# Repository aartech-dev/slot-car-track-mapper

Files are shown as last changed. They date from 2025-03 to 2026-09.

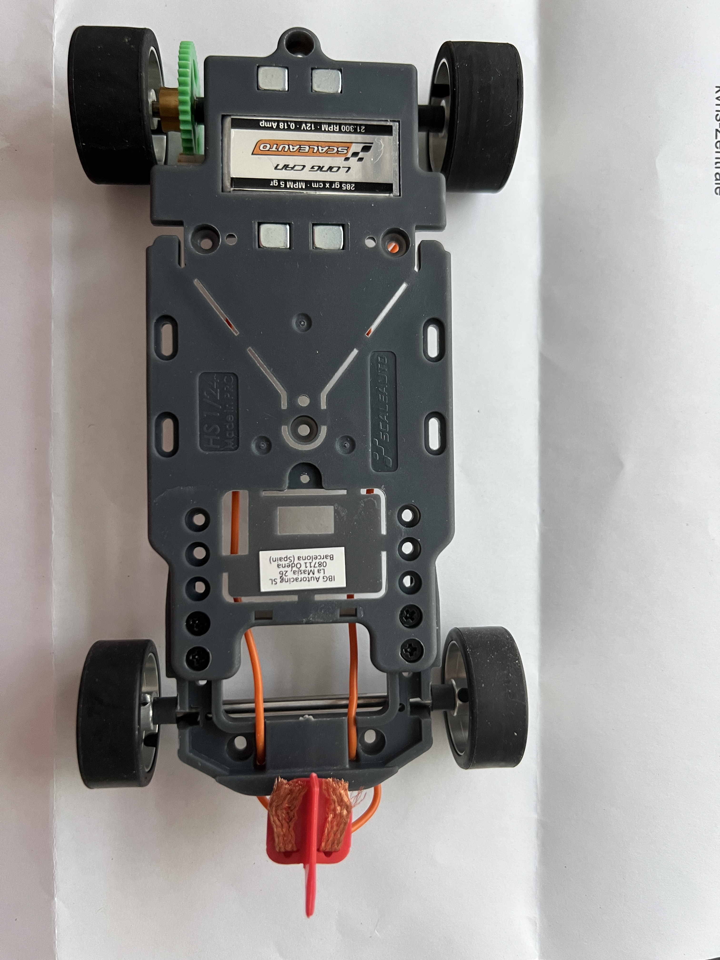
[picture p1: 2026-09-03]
tmp/scaleauto-chassis-bot.jpeg

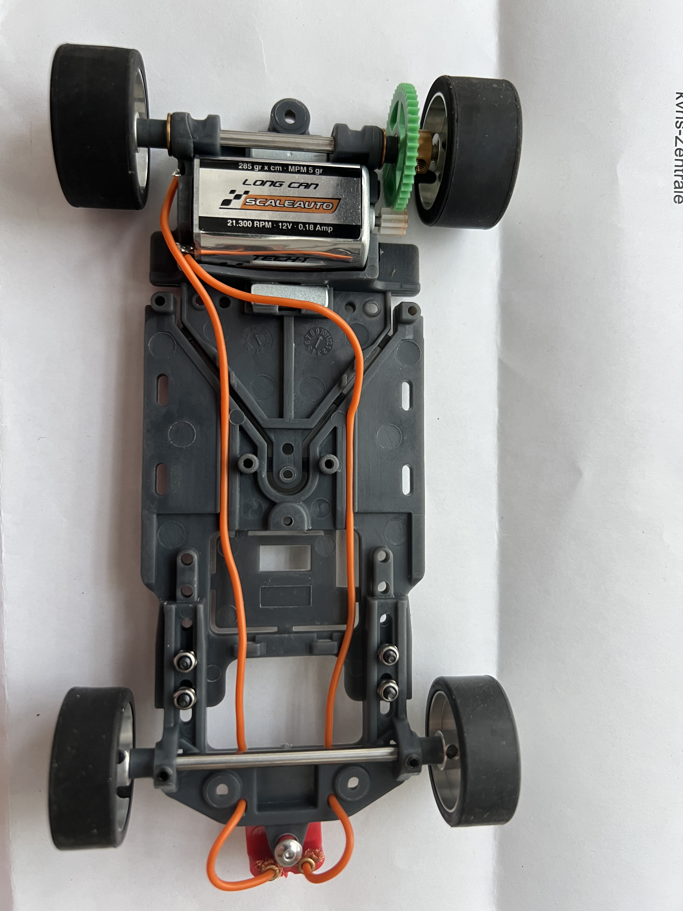
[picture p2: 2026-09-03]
tmp/scaleauto-chassis-top.jpeg

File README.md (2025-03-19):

# slot-car-track-mapper
Design for a device for mapping a slot car track by using a part from an optical mouse.

## Links

https://github.com/KMKfw/kmk_firmware/blob/main/kmk/modules/adns9800.py

https://hackaday.com/tag/adns-9000/

https://www.application-datasheet.com/pdf/broadcom/adns-6190-002.pdf   

https://www.tindie.com/products/citizenjoe/adns-9800-motion-sensor/   

https://www.reddit.com/r/Trackballs/comments/ovn849/sharing_adns9800_and_pmw3360_breakout_boards_on/   

https://sminliwu.github.io/2019/04/30/adns.html

https://github.com/kbjunky/ADNS9800   

http://pepijndevos.nl/2015/05/29/adns-9800-hookup-guide.html  

https://www.instructables.com/Arduino-Tutorial-ADNS-9800-Laser-Mouse-Traveled-Di/  

https://github.com/INITIAL7664/ADNS-9800/blob/master/firmware.ino

https://github.com/svofski/ADNS-9800-Energia/blob/master/ADNS-9800-Energia.ino

https://8051enthusiast.github.io/2020/04/14/001-USB_Firmware.html

https://github.com/mrjohnk/ADNS-9800/tree/master

https://github.com/joshuajnoble/ArduinoADNS-9800/blob/master/ADNS9800.ino

```

from machine import Pin, SPI
import time

# SPI Setup
SPI_CLK = 10
SPI_MOSI = 11
SPI_MISO = 12
CS_PIN = 13
RESET_PIN = 14

# ADNS-9800 Registers
REG_PRODUCT_ID = 0x00
REG_MOTION = 0x02
REG_DELTA_X = 0x03
REG_DELTA_Y = 0x04
REG_SROM_ENABLE = 0x13
REG_SROM_ID = 0x2A
REG_SROM_LOAD_BURST = 0x62
REG_LASER_CTRL0 = 0x20

# SPI Initialization
spi = SPI(1, baudrate=2000000, polarity=1, phase=1, miso=Pin(SPI_MISO), mosi=Pin(SPI_MOSI), sck=Pin(SPI_CLK))
cs = Pin(CS_PIN, Pin.OUT, value=1)
reset = Pin(RESET_PIN, Pin.OUT, value=1)

def write_register(register, value):
    cs.value(0)
    spi.write(bytearray([register | 0x80, value]))  # MSB = 1 for write
    cs.value(1)
    time.sleep_us(50)

def read_register(register):
    cs.value(0)
    spi.write(bytearray([register & 0x7F]))  # MSB = 0 for read
    time.sleep_us(50)
    data = spi.read(1)
    cs.value(1)
    return data[0]

def reset_sensor():
    reset.value(0)
    time.sleep_ms(10)
    reset.value(1)
    time.sleep_ms(10)

def upload_srom(srom_data):
    write_register(REG_SROM_ENABLE, 0x1D)
    time.sleep_ms(10)

    write_register(REG_SROM_ENABLE, 0x18)
    time.sleep_ms(10)

    cs.value(0)
    spi.write(bytearray([REG_SROM_LOAD_BURST | 0x80]))  # Start burst mode write
    time.sleep_us(15)

    for byte in srom_data:
        spi.write(bytearray([byte]))
        time.sleep_us(15)

    cs.value(1)
    time.sleep_ms(10)

def read_motion():
    motion = read_register(REG_MOTION)
    if motion & 0x80:  # Motion detected
        delta_x = read_register(REG_DELTA_X)
        delta_y = read_register(REG_DELTA_Y)
        return (delta_x, delta_y)
    return (0, 0)

# --- Main Execution ---
reset_sensor()

# Check product ID
prod_id = read_register(REG_PRODUCT_ID)
if prod_id != 0x33:
    print(f"Error: Unexpected Product ID {prod_id:#02x}")
else:
    print(f"ADNS-9800 detected! Product ID: {prod_id:#02x}")

# Load SROM (You need to replace 'srom_data' with actual SROM file contents)
srom_data = bytes([0x00] * 4094)  # Replace this with real SROM data
upload_srom(srom_data)

# Verify SROM
srom_id = read_register(REG_SROM_ID)
if srom_id == 0:
    print("Error: SROM upload failed.")
else:
    print(f"SROM successfully loaded. ID: {srom_id:#02x}")

# Enable Laser
write_register(REG_LASER_CTRL0, 0x80)  # Enable laser

# Main Loop to Read Motion
while True:
    dx, dy = read_motion()
    if dx != 0 or dy != 0:
        print(f"Motion detected: ΔX={dx}, ΔY={dy}")
    time.sleep(0.1)

```

## How to Use

Copy the script onto your Raspberry Pi Pico using Thonny or another MicroPython editor.
Ensure you have the ADNS-9800 SROM file (from PixArt). Replace srom_data with the actual bytes from the SROM.
Run the script. If the sensor is properly connected, you should see motion data when you move it.

## Next Steps
Fine-tune DPI settings by adjusting configuration registers.
Implement more advanced features, such as lift detection or angle snapping.
Store the real SROM file in flash memory or an SD card instead of embedding it in code.

To use the ADNS-9800 SROM file in MicroPython, you need to:

Obtain the SROM file (usually a .bin file) from PixArt or an official source.
Convert it to a byte array that MicroPython can read.
Modify the script to read the file from flash storage or an SD card.

Step 1: Convert the SROM File
If you already have the ADNS9800_SROM.bin file, you need to convert it into a Python byte array. You can do this with a Python script on your computer.

Convert SROM File to Python Byte Array

Run this Python script on your computer (not on the Pico!):

```
# Convert ADNS-9800 SROM binary to a Python byte array
srom_filename = "ADNS9800_SROM.bin"

with open(srom_filename, "rb") as f:
    srom_data = f.read()

# Format as a Python list
output = "srom_data = bytes([" + ", ".join(f"0x{b:02X}" for b in srom_data) + "])"

# Save as a Python file
with open("srom_data.py", "w") as f:
    f.write(output)

print("Conversion complete! The SROM data is saved in 'srom_data.py'.")
```

This script reads the binary file and converts it into a Python byte array.
The output is stored in srom_data.py, which you can then upload to the Pico.

Step 2: Upload the SROM Data to the Pico
After running the script, copy srom_data.py to your Raspberry Pi Pico.
Modify your MicroPython script to import the SROM data instead of defining it manually.

Step 3: Modify the MicroPython Script to Use the SROM File
Change this line in your MicroPython script:
```
srom_data = bytes([0x00] * 4094)  # Replace this with real SROM data
```

To this:
```
from srom_data import srom_data  # Import the converted SROM data
```

Alternative: Read Directly from an SROM File on an SD Card
If you have an SD card connected to the Pico, you can store the ADNS9800_SROM.bin there and read it directly:
```
def load_srom_from_sd():
    with open("/sd/ADNS9800_SROM.bin", "rb") as f:
        return f.read()

srom_data = load_srom_from_sd()
```

Final Steps
Run your MicroPython script on the Pico.
The SROM should now load properly, and the sensor should start tracking motion! 🚀
```
import os
import sdcard
import machine
import time

# SD Card SPI Configuration
SPI_SD = machine.SPI(0, baudrate=1000000, polarity=0, phase=0,
                     sck=machine.Pin(18), mosi=machine.Pin(19), miso=machine.Pin(16))
CS_SD = machine.Pin(17, machine.Pin.OUT)

# Mount SD Card
def mount_sd():
    global sd
    try:
        sd = sdcard.SDCard(SPI_SD, CS_SD)
        vfs = os.VfsFat(sd)
        os.mount(vfs, "/sd")
        print("SD Card Mounted!")
    except Exception as e:
        print("Failed to mount SD card:", e)

# Load SROM File from SD Card
def load_srom_from_sd(filename="/sd/ADNS9800_SROM.bin"):
    try:
        with open(filename, "rb") as f:
            srom_data = f.read()
        print(f"SROM file loaded: {len(srom_data)} bytes")
        return srom_data
    except Exception as e:
        print("Error reading SROM file:", e)
        return None

# --- MAIN EXECUTION ---
mount_sd()

srom_data = load_srom_from_sd()
if srom_data:
    print("SROM Data Ready to Upload to ADNS-9800!")
else:
    print("Failed to load SROM file.")
```

4. Upload the SROM File to the SD Card

Format the SD card as FAT32.
Copy the ADNS9800_SROM.bin file to the root of the SD card.
Insert the SD card into the Pico SD card module.

5. Modify Your ADNS-9800 Code

Now, update your ADNS-9800 MicroPython script to read from the SD card:

Replace this:
```
from srom_data import srom_data  # Import the SROM from a Python file
```
With this:
```
srom_data = load_srom_from_sd()
```

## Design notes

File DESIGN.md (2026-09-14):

# Design Document: Slot Car Track Mapper

Status: concept / pre-implementation. This document captures the reasoning behind the chosen sensing approach and the electrical design, so mechanical/fixture and firmware work can proceed from a shared plan instead of ad hoc experimentation.

## 1. Goal

Reconstruct the 2D shape (path) of a slot car track by carrying a sensor package around the track in a car, without any prior knowledge of the track layout. A real track has multiple parallel lanes (routed slots), and the goal is an accurate vector representation of *every* lane, not just the one driven first — §9 covers how the single-lane pipeline in §2–§8 extends to that, and what it still needs (a small manual measurement, not more sensing) to get there.

## 2. Why optical flow alone is not enough

A single optical-mouse sensor (ADNS-9800, PMW3360, PAW3395, HERO, ...) reports incremental surface displacement **in its own body-fixed axes**, not in world coordinates. A slot car follows the guide slot, so the chassis — and a sensor bolted to it — yaws to track every curve. Through most of a corner the sensor therefore sees close to pure "forward" flow, the same as on a straight. Summing those local (dx, dy) vectors as if they were already in a fixed world frame collapses curves toward straight lines: the sensor isn't wrong, it's just reporting *distance traveled*, not *track curvature*.

To recover the true path you need a heading (yaw) estimate at every sample, so each local displacement can be rotated into world coordinates before it's integrated — standard dead-reckoning. Two ways to get that heading:

1. **IMU fusion (chosen approach).** Add a gyroscope (part of any 6/9-axis IMU) and integrate yaw rate into heading. Rotate each optical (dx, dy) sample by the current heading, then accumulate world-frame position. Single sensor, single extra part, runs entirely as a firmware fusion loop on the Pico.
2. **Dual optical sensors.** Two sensors at a fixed baseline; differencing their along-track readings gives rotation directly (same principle as differential wheel-encoder odometry), no IMU needed. Rejected for v1: doubles SPI wiring and pin budget, and needs precise mechanical spacing on a 1/24-scale fixture.

Mechanical note: ideally the sensor sits directly over the car's guide-pin pivot, since that's the point whose velocity is "pure" body-frame translation. If it's offset by a vector **r** (likely, given fixture constraints), the sensor also picks up a lever-arm term from rotation: `v_sensor = v_pivot + ω × r`. Once ω (from the IMU) and **r** (measured once, fixed) are known this is a straightforward correction in the fusion loop, but **r** needs to be measured accurately when the fixture is built.

The current first-pass CAD layout (§7, `cad/fixture.scad`) places the PMW3360 18mm back from the guide-pin pivot — so `r ≈ 18mm` along the chassis centerline is the current working value for this correction, pending the layout settling down as real part dimensions replace the estimates.

## 3. Selected parts

| Role | Part | Why |
|---|---|---|
| Microcontroller | **Raspberry Pi Pico 2 W** | RP2350: same CYW43439 WiFi as plain Pico W, so `wifimanager.py`'s `network.WLAN` code runs unmodified — chosen over an ESP32 to avoid WiFi-radio scheduling jitter competing with the sensor-fusion polling loop on the same cores. Adds a hardware FPU (Cortex-M33, unlike the RP2040/original Pico's M0+), which directly speeds up the fusion loop's per-sample rotation trig (§6). 520KB SRAM (vs. RP2040's 264KB) gives headroom for the path buffer/logging. Same Pico form factor and largely the same GPIO layout as the original Pico, so `main.py`'s existing pin constants likely carry over without remapping. Considered and rejected: ESP32 (mature MicroPython WiFi, but shares compute with the sensor loop, and requires a full pin remap), Arduino Nano RP2040 Connect (tempting onboard IMU, but its WiFi is a separate NINA module without native MicroPython `network` support — would break `wifimanager.py`). |
| Optical flow sensor | **PMW3360** | Large open-source driver base from mouse-modding/DIY-odometry projects. Performance is comparable to ADNS-9800 and well beyond what slot car speeds need either way. **Correction:** this row originally also claimed "no mandatory SROM firmware upload" as a reason to prefer it over the ADNS-9800 — that's wrong. Every reference PMW3360 driver uploads an SROM firmware blob on power-up via `SROM_Load_Burst`, the same as the ADNS-9800 (see `pmw3360.py`). The SROM step doesn't go away; it just isn't a *worse* bring-up than the ADNS-9800's, so it wasn't actually a differentiator either way. |
| IMU | **ICM-42688-P** | 6-axis gyro+accel with notably lower gyro bias/noise than the ubiquitous MPU6050 — directly reduces the heading-integration drift that's the main source of mapping error in this design (§2). Similar price/I2C-breakout availability to MPU6050. |

The optical sensor and IMU were chosen over alternatives considered (ADNS-9800 kept for reuse, PAW3395 for raw performance, MPU6050 for ubiquity, BNO085 for onboard fusion) mainly on integration risk vs. payoff at this project's actual requirements — see conversation history for the full comparison if reconsidering later.

**Consequence:** `main.py`'s ADNS-9800 SPI register map and `a6_binary.py`'s extracted SROM firmware are now superseded, replaced by `pmw3360.py`'s PMW3360 driver — including its own real SROM 0x04 firmware (sourced from SunjunKim/PMW3360, no longer a placeholder). `a6_binary.py` is left in place as a worked reference for the general SPI-register bring-up pattern (reset → verify product ID → init → poll) and the vendor-SROM-to-Python-array conversion technique it demonstrated, both of which carried over, along with the pin constants (subject to confirming the Pico 2 W's pinout matches).

### Electrical schematic and concrete pin assignments

`electronics/electronics.kicad_sch` is the single-sheet system schematic covering every component above plus the power chain (§4): rail input → reverse-polarity diode → buck-boost regulator → Pico VSYS, with a supercap on the regulated 5V rail and an unmodified tap to the stock motor. The PMW3360, ICM-42688-P, IR reflectance sensor, and the buck-boost regulator don't have real breakout-specific KiCad symbols, so they're drawn as generic pin-header connectors labeled by net — see the file's own text notes for what's a real part symbol (Pico 2 W, using the pin-compatible RP2040 `RaspberryPi_Pico` library symbol) versus a documentation stand-in. Passes ERC clean (0 violations) with explicit no-connect flags on every intentionally-unused pin.

Cross-checked against Ploopy's open-hardware trackball designs (`ploopyco/classic-trackball`, CERN-OHL-1.2, `hardware/Electronics/Schematics/Base-R1_005.pdf`), which wire the bare PMW3360DM-T2QU chip directly on a real shipped product. Their `MouseSensor.SchDoc` needs three separate rails — VDD 1.8V, VDDIO 3.3V (matched to host logic), and VDDPIX 1.8V fed through a 22Ω+22Ω filter with 10uF/0.1uF decoupling right at the pin — plus a 10k pull-up from CS to 3V3 so the sensor stays deselected before the MCU's GPIO drives it high. That VDDPIX filtering requirement is a concrete reason this project's plan to buy a PMW3360 *breakout* (BOM.md) rather than lay out the bare chip is the right call — a decent breakout hides that three-rail circuit behind its own onboard 1.8V regulator and exposes a single VCC. Two things worth carrying over onto our own board regardless: add the same CS-to-3V3 pull-up once a real PMW3360 breakout symbol replaces the generic connector (§8), and when that breakout is actually sourced, check whether it truly hides VDD/VDDIO/VDDPIX internally or expects them wired separately — cheap DIY-mouse-mod modules vary on this.

Drawing it forced concrete GPIO assignments, which now supersede the vague "SPI0"/"I2C0" labels used earlier in this document:

| Signal | Pico 2 W pin |
|---|---|
| SPI0 SCK / MOSI / MISO / CS → PMW3360 | GPIO10 / GPIO11 / GPIO12 / GPIO13 |
| PMW3360 MOTION (interrupt) | GPIO14 |
| I2C0 SDA / SCL → ICM-42688-P | GPIO4 / GPIO5 |
| ICM-42688-P interrupt | GPIO6 |
| IR reflectance sensor output | GPIO26 (ADC0) |

The SPI pins land on the exact same GPIOs `main.py` already uses for the ADNS-9800 (`SPI_CLK=10, MOSI=11, MISO=12, CS=13`) — but GPIO14, previously the ADNS-9800's `RESET_PIN`, is repurposed as the PMW3360's motion-interrupt input (the PMW3360 has no reset pin). That's a change in *meaning*, not just reuse — flag it clearly when the firmware is rewritten so it isn't mistaken for a leftover reset line.

Per §2's environmental note: configure the ICM-42688-P (or any future IMU swap) for gyro+accel only — no magnetometer is on this part, so the mag-interference risk from the motor magnets doesn't apply here, which is one more point in its favor over 9-axis parts.

## 4. Power: analog controllers change the constraint

Confirmed: controllers are analog (resistive/linear throttle), not PWM. That means rail voltage is a clean, un-chopped DC level — but one that is *intentionally* proportional to trigger position, from ~0 V (stopped) up to full pack voltage (typically 12–18 V) at full throttle. This is a harder power problem than a PWM system, not an easier one: there is no fixed high-frequency carrier to hold electronics up between pulses, because at low throttle there may genuinely be almost no rail voltage at all.

Implications:

- A simple buck regulator won't work across the whole range — it can't produce 3.3/5 V once the input sags below its dropout, which will happen exactly when the car is slow or stopped.
- A **buck-boost** regulator (e.g. TI TPS63070-class, ~0.9–18 V in) extends the usable range down much further, but still has a floor near true 0 V.
- Below that floor, only stored energy keeps the electronics alive.
- No shortcut via a separate accessory rail: slot car tracks never carry a third, constant-voltage rail alongside the two throttle rails — cars with lights or other accessories run them off the same variable throttle rail, not an independent supply. So the buck-boost + supercap design below is the actual answer to this problem, not a fallback for when a nonexistent easier option isn't available.
- Include basic input protection (reverse-polarity diode / small TVS) regardless of source — pickup shoes can momentarily bridge or reverse polarity on crashes/spin-outs.

### Energy buffer: supercapacitor (selected)

**Decision: a single supercapacitor, not a LiPo battery**, sized to ride through brief low-throttle/contact-loss moments during an active mapping lap — not to keep the device alive for extended parked periods, which isn't this project's requirement. Reasoning:

- **Simplicity:** a supercap needs no charge-management *IC*, no protection circuit, and no power-path chip — at most a resistor and a diode (below), not a dedicated chip. A LiPo needs all three (charger IC, protected cell, ideally a power-path chip to avoid a hard switchover between rail power and battery power) for a small cost/weight saving that doesn't matter here.
- **Crash safety:** slot cars hit barriers. A punctured/crushed LiPo pouch is a real fire risk; a damaged supercap is not. This matters more here than in most projects.
- **Fit to duty cycle:** supercaps self-discharge faster than LiPo and don't hold charge for long-term storage — irrelevant for a device that's only ever active while running on the track, where it's continuously recharged during every high-throttle segment.

**Placement — regulator output, not regulator input:** don't connect the supercap directly across the raw rail; the rail swings up to full pack voltage (12–18 V), well above a single 5.5 V-rated cell, and multi-cell series stacks need balancing (reintroducing the complexity being avoided). Instead:

```
rail → [buck-boost regulator] → 3.3V/5V logic rail → Pico/sensors
                                        |
                                  [R1] (charge current limit)
                                   |       |
                                  [D2] ---‖ (bypasses R1 when the cap is
                                   |          discharging — ride-through
                              [supercap]     current isn't limited by R1)
```

Size the cap with `C = I × t / ΔV`: at a rough 80–100 mA logic load, accepting the rail sagging from 3.3 V to ~2.7 V before it's risky, a 1 F/5.5 V cell (~$1–2) buys a few seconds of full ride-through with zero rail voltage; a 10 F/5.5 V cell (~$2–5) buys tens of seconds.

**Charging isn't free, though, and it isn't just "the regulator's current limit handles it."** Connecting a fully-discharged cap directly to a live regulator output looks like a near dead-short for the first instant — worth limiting explicitly rather than trusting an unspecified regulator's behavior. `electronics/electronics.kicad_sch` adds:

- **R1** (provisionally 4.7Ω) in series between the regulated rail and the cap, limiting charge inrush.
- **D2** (Schottky) in parallel with R1, oriented so the cap can *discharge* back into the rail through D2's low forward drop instead of through R1 — otherwise R1 would eat into the very ride-through voltage margin the cap exists to provide.

This means charge time is now an `R1 × C1` problem, not just a regulator-current problem — and it cuts the other way from the ride-through sizing above: `t_charge ≈ 5 × R1 × C1` (5 time constants ≈ full charge). With R1 = 4.7Ω: a **1F cap charges in ~24s**; a **10F cap would take ~4 minutes** — long enough that the device wouldn't have its ride-through protection for the first few minutes of every session. **This pushes the practical choice toward the 1F end of the range above, not the 10F end**, unless R1 is reduced (which weakens inrush protection) — the two were sized independently earlier in this doc and need to be sized together. Revisit both once a real regulator's current limit is known (its datasheet may make R1 unnecessary or let it shrink).

**Reconsider LiPo only if** the requirement changes to "must stay powered for minutes with no rail contact" (e.g. logging while parked in the pits) — a supercap can't do that in a small/cheap package. If that happens: single protected 1S cell (100–150 mAh) + a linear charger IC (MCP73831-class) + ideally a power-path chip (BQ24075-class) to charge and run simultaneously without switchover glitches. Budget for ongoing battery-health concerns then too (over-discharge cutoff, cycle-life fade, no long-term full/empty storage).

See `electronics/electronics.kicad_sch` for the R1/D2/C1 sub-circuit as drawn (ERC-clean).

## 5. System block diagram (IMU fusion option)

```
                    TRACK RAILS (analog DC, ~0-18V, varies with throttle)
                              |                    |
                              v                    v
                   +---------------------------------------+
                   |     Pickup shoes / contact braids      |
                   +---------------------------------------+
                              |                    |
                              v                    v
        +----------------------------------------------------------+
        |          reverse-polarity protection (diode/TVS)          |
        |          buck-boost regulator, Vin ~0.9-18V -> 3.3V/5V    |
        +----------------------------------------------------------+
                              |
                              v  regulated 3.3V/5V rail
                              +---------------------------+
                              |  supercap (5.5V-rated),    |
                              |  rides out low-throttle /  |
                              |  contact-loss dips         |
                              +---------------------------+
                              |
        +----------------------------------------------------------+
        |               Raspberry Pi Pico 2 W (RP2350)               |
        |                                                            |
        |  SPI0 (CLK/MOSI/MISO/CS, RESET) -------------------------->|---> Optical flow sensor
        |                                                            |     (PMW3360) mounted over
        |                                                            |     track surface, at/near
        |                                                            |     guide-pin pivot
        |                                                            |
        |  I2C0 (SDA/SCL) ------------------------------------------>|---> IMU (ICM-42688-P,
        |                                                            |     gyro + accel), rigidly
        |                                                            |     mounted, axes aligned to
        |                                                            |     chassis forward/lateral/
        |                                                            |     vertical
        |                                                            |
        |  GPIO/ADC ------------------------------------------------>|---> IR reflectance sensor
        |                                                            |     (TCRT5000/QRE1113),
        |                                                            |     mounted alongside PMW3360,
        |                                                            |     reads start/finish marker
        |                                                            |
        |  [optional] SPI1/SD -------------------------------------->|---> onboard logging (SD/flash)
        |  [optional] onboard WiFi (wifimanager.py) ----------------->|---> base station / laptop
        +----------------------------------------------------------+
```

## 6. Firmware fusion loop

Implemented in `main.py` (with `pmw3360.py` and `icm42688.py` as the sensor drivers) — not yet tested on real hardware, see those files' own caveats. Per sample tick:

1. Read gyro yaw rate from IMU; integrate into heading `θ`.
2. Read (dx, dy) from optical sensor (body frame); apply the lever-arm correction `v_pivot = v_sensor − ω × r` using this tick's rotation and the measured mounting offset **r** = 18mm (CAD, §2, §7).
3. Rotate the corrected (dx, dy) by `θ` into world coordinates; accumulate into running position (X, Y).
4. Write (t, X, Y, θ, lap) as a CSV row to flash on every tick, flushed every 50 samples — chosen over "buffer everything, write once at the end" specifically because this project's own power story (§4) means a mid-run brownout is a real, not theoretical, risk; buffering it all in RAM would lose an entire run to a single dropout.
5. On lap-trigger detection (below), reset accumulated position to (0, 0) — the marker's own location, since that's what defines the origin; heading `θ` is left as-is (the trigger carries no direction information — see below).

Calibration this first pass still needs (not yet possible without hardware in hand): `LAP_THRESHOLD` tuned against the real IR marker's light/dark ADC values, and a by-hand sanity check that the gyro sign and the optical sensor's dx/dy axes match the code's assumed convention (documented at the top of `main.py`) — get either wrong and the map will be systematically distorted in a way that's easy to misattribute to the physics instead. (The PMW3360 SROM firmware is no longer on this list — `pmw3360.py` now has the real SROM 0x04 blob, not a placeholder.)

`pmw3360.py`'s driver has also been cross-checked against QMK's PMW33xx driver (`qmk/qmk_firmware`, `drivers/sensors/pmw3360.c`/`pmw33xx_common.c`), deployed on real trackball keyboards using this sensor. QMK doesn't carry the SROM byte content in-tree either (dropped for licensing, opt-in and keyboard-supplied from this same SunjunKim/PMW3360 source), so it can't confirm `SROM_FIRMWARE` byte-for-byte — but its constants do corroborate it: firmware length (4094 bytes) and product/inverse-ID signature (0x42/0xBD) both match, and its register map agrees address-for-address. Two init-sequence details this port was missing got folded in as a result: the NCS power-up toggle before `Power_Up_Reset`, and more conservative post-write settle timing — both proven across QMK's real-hardware deployments, still unverified here on this project's own board.

### Gyro-bias calibration (at power-up)

**Implemented in `main.py` as `calibrate_gyro_bias()`, run once at startup before the fusion loop begins.** `sim/simulate_track_run.py` (built to generate expected sensor data for the real Bolton club track, §6/§8) modeled a deliberately modest, realistic 0.3°/s uncalibrated gyro bias and found it responsible for roughly **320mm of reconstructed-position error by the end of a single 12.5s lap** (isolated by re-running the simulation's own closing-error check with the bias zeroed: ~1080mm with the bias present vs. ~750mm without it) — comparable to, and in the same direction as, the optical sensor's own noise contribution. *Correction: an earlier version of this section attributed the entire ~1.1m closing error to gyro bias alone; isolation testing during implementation showed the remaining ~750mm is a baseline artifact of the simulation script's own heading-synthesis method (see `HEADING_WINDOW_MM`'s caveat comment in `sim/simulate_track_run.py`), not something attributable to gyro bias, noise, or a defect in the fusion algorithm itself — flagged in case a future pass re-derives these numbers and gets a different split.* Either way, the lap-reset (below) hides the bias's within-lap effect by zeroing (X, Y) at each marker crossing, but it does nothing for heading, which keeps accumulating the same bias lap after lap; any use of the map beyond "one lap's shape" (comparing laps, averaging them, trusting absolute heading) needs this fixed at the source.

**Design (as implemented):**

1. **Before the run starts, with the car held stationary** (on the bench or sitting still in the slot), sample the gyro Z axis for a short fixed window (`GYRO_CAL_DURATION_MS`, 1.5s) and average the readings to estimate the static bias `gz_bias`.
2. **Subtract `gz_bias` from every raw gyro reading** before integrating it into heading, for the remainder of that run. This runs fresh at the start of every `run()` call rather than storing a calibration constant across runs/power cycles — gyro bias drifts with temperature and time, so yesterday's measured bias is not a safe stand-in for today's.
3. **Verify stillness during the calibration window** using the accelerometer already being read for other purposes (§3/§6) — `calibrate_gyro_bias()` checks its combined variance over the window against `GYRO_CAL_MAX_ACCEL_STD_G` and prints a `MOVED -- calibration unreliable` warning rather than silently baking a bad bias into the whole run (it doesn't yet block/retry the run automatically — that's a possible follow-up once real accelerometer noise floor data says what threshold is actually reliable).
4. **Limitation, by design:** this corrects the *static* bias present at power-up, not in-run bias wander — it's a start-of-run correction, not a continuous one. A zero-velocity update (detecting known-stationary moments during a run, e.g. the car briefly stopped) would address in-run wander if it turns out to matter — not needed for v1, noted here so it isn't forgotten if lap-to-lap heading error looks worse than this calibration alone can explain.

### Closed-loop heading correction (offline, per completed lap)

At-rest calibration (above) only removes the bias present *before* the run starts — it does nothing for bias that wanders during the run, and `tools/plot_track_csv.py`'s overlay view made the consequence visually obvious: the reconstructed path bows away from the true track shape, worst through the tightest sections, because nothing ever corrects *heading* mid-lap (only position resets, at the marker).

**The fix needs no new hardware, because a lap is a closed curve.** The car's net heading change over one complete lap is a known geometric quantity, not a free parameter — for a lane whose own centerline is a simple loop (no self-crossing), it's exactly ±360° per lap; for a lane that crosses itself once, it's a different, still-computable value (0° for a simple figure-8-style self-crossing). Whatever it is, the *difference* between that known value and what the lap's logged heading actually did is attributable to gyro bias/wander during that lap, and can be removed by re-integrating the whole lap with a constant correction spread over its elapsed time.

**Important nuance on what "crosses itself" means, since most real tracks have a crossover:** a lane-swap crossover piece (common — used to equalize total lane lengths, since a permanent inside lane would otherwise be shorter than the outside one) makes one lane's centerline cross *another lane's*, not its own. Each individual lane is typically still a simple loop (±360° net turn) despite the crossover. Only a lane whose *own* centerline genuinely loops back and crosses itself gets a different value — determine which case applies by inspecting the actual driven lane, not just whether the track has a crossover piece at all. `tmp/bolton-track.svg`'s "yellow" lane, used throughout this project's simulation, turns out to be the self-crossing case: computing its net turning directly from the SVG geometry (not guessed) gives exactly **0°**, not ±360° — confirming this needs checking per track, not assumed.

**Implemented as `tools/closed_loop_correct.py`, run offline on a downloaded `track_log.csv`, not on-device.** It turns out no firmware change is needed to support this: `main.py` already logs `theta_rad` continuously (never reset, only `x`/`y` reset at the marker), so the raw per-tick heading change is recoverable directly from consecutive log rows, and the per-tick body-frame translation is recoverable by inverse-rotating consecutive `(x, y)` deltas by the logged `theta_rad` — enough to fully re-integrate a lap with a corrected heading trace. This also keeps the correction properly offline: it needs a *complete* lap's total turning and elapsed time before it can compute anything, which doesn't fit `main.py`'s incremental streaming-write design (deliberately real-time and brownout-safe, §6) — so it stays a separate post-processing step rather than something attempted live on the Pico.

**Validated in simulation** (`sim/simulate_track_run.py` now also emits `sim/expected_firmware_log.csv`, formatted exactly like the real on-device log, for this purpose): running `tools/closed_loop_correct.py --net-turns 0.0` on that simulated log reduced the closing error from ~1120mm to ~700mm (roughly **-40%**), and reduced the worst-point deviation from the true path by a comparable margin. It does not eliminate the error — the remainder is gyro random-walk noise (not fixable by a constant per-lap correction) plus a heading-synthesis artifact specific to how the simulator generates its synthetic gyro data.

**Lap length, and multi-lap averaging.** The same tool reports each corrected lap's length in meters (arc length of its own reconstructed path) and the mean/spread across however many laps were recorded — on a simulated 5-lap run this came out as 36.349m mean with only a 32mm spread lap-to-lap, close to (though not exactly) the track's true 35.9664m (118ft), the residual gap being the same heading-synthesis artifact mentioned above. `--average-out` additionally resamples every corrected lap onto a common arc-length parameterization and averages them into one smoothed shape, for a visually cleaner map — but its own length figure isn't more trustworthy than the simple per-lap mean: it came out to ~36.9m on the same test data, higher than the 36.349m mean, because the averaging doesn't correct for small heading-orientation differences between laps before combining them. Use the per-lap mean as the lap-length measurement; treat the averaged shape as a visualization aid. The full data-collection-to-post-processing procedure is `BRINGUP.md` Stage 11.

### Lap-detection mechanism (selected)

**Decision: onboard active-IR reflectance sensor (e.g. TCRT5000/QRE1113-class) reading a physical contrast marker (tape strip) laid across the track at the start/finish line.** Mounted on the car alongside the PMW3360, near the guide-pin pivot — the guide pin tightly constrains lateral position, so the sensor sweeps the same physical point on the marker every lap with no alignment tolerance needed.

Rejected alternatives and why:
- **Software-only ("near starting X,Y after N seconds")** — circular: uses the very dead-reckoned position that's drifting to decide when to correct it. Breaks outright on a self-crossing layout (figure-8), where "near start" is ambiguous.
- **Hall sensor + embedded magnet** — the motor's own permanent magnets sit right next to the mounting location; a simple threshold Hall switch can't reliably separate "external track magnet passing underneath" from "background field from my own motor." Same interference family already ruled out for magnetometer fusion (§3).
- **Mechanical lever/bump strip** — physical obstruction on the track, wear over many laps, risk of inconsistent engagement (bounce/skip).
- **External trackside IR gate** — moves the sensor off the car, but the correction has to be applied *onboard* where the dead-reckoning state lives, so it still needs a real-time wireless link back to the car, plus trackside alignment every time the layout is reconfigured. More moving parts than a sticker.

Active-IR reflectance (emits and reads its own reflected IR) is immune to ambient lighting, unlike a bare phototransistor, and the module is sub-$1 with a simple GPIO/ADC read.

**Limitation:** a single marker crossing gives a position reference only, not heading — heading keeps relying on the ICM-42688-P's gyro integration between corrections. If heading drift becomes visible over many laps, a second marker a short known distance downstream would let the time-of-flight between the two triggers derive an instantaneous heading correction too — a future upgrade, not needed for v1.

**Debounce:** ignore any trigger occurring less than some fraction of the expected lap time since the last one, so a wide/uneven marker edge or a bounce doesn't double-fire the correction.

**Tape width — size it to the sampling, not just to "wide enough to see":** `main.py`'s loop is unthrottled (no `sleep()`), so its real sample period is whatever SPI+I2C+math+logging overhead works out to on real hardware — not yet measured (§8). `sim/simulate_track_run.py`, at its 100Hz assumption and ~3 m/s tape-crossing speed, showed only **1 sample** landing above `LAP_THRESHOLD` with a 12mm tape — a single missed sample (loop jitter, a slightly faster pass) means a missed lap entirely.

The sizing rule: for a loop sampling at period `T` and a car crossing at speed `v`, any tape narrower than `v·T` (in the direction of travel) can fall entirely between two samples and be missed outright; `2·v·T` guarantees at least one sample with some margin either side of exact alignment. E.g. at `v`=3–6 m/s and an assumed `T`=10ms (100Hz, itself unverified — see above): 30–60mm for a bare guarantee, 60–120mm for margin.

**Recommendation: start with a 40mm-wide tape strip** (re-confirmed against `sim/simulate_track_run.py`, which now catches 2 samples at its simulated pace with this width) as a practical starting point, and revisit against the *measured* loop period once real hardware timing is in hand (§8) — narrower is fine if the real loop turns out faster than 100Hz, wider is needed if slower. Driving a controlled, less-than-flat-out pace specifically across the line (lower `v` at the crossing) directly buys the same margin as a wider tape, per the same formula, and costs nothing to try first.

## 7. Fixture: donor chassis conversion

**Donor:** Scaleauto HS-124 Universal Complete Chassis (plastic, sidewinder, variable wheelbase 96–114mm). Measured on the chassis in hand: wheelbase 114.25mm, rear track width (outside-to-outside) 80.72mm, front track width (outside-to-outside) 77.83mm, main chassis spine width 55mm, V score-line to (former) front axle centerline 47mm, front axle centerline to guide-flag tip 18mm, spine plastic thickness at the cut face 3.6mm, guide-flag pivot peg 3.8mm diameter × 7mm engagement depth. Sidewinder layout: motor mounted along the chassis's long axis driving the rear axle through a pinion/spur gear pair; guide flag at the front doubles as the mechanical slot-engagement piece *and* the power pickup (its braids feed two wires running the full chassis length back to the motor terminals).

**The caliper measurements matter beyond just accuracy:** the replaceable front section is only 65mm long (47+18mm) — barely half of the ~112mm first guessed from photos. That's tight enough to change the layout, not just tune it: the Pico 2 W's 51mm length alone would eat most of the available space if mounted the "normal" way (long axis along the direction of travel), so `cad/fixture.scad` now mounts it rotated 90° — long axis running across the fixture's width — trading length for width, which the flared deck has to spare. See the CAD subsection below.

**Plan:** cut the chassis at its molded score line ("the V") in front of the motor box. Keep the rear section (motor + driven axle/wheels) stock and unmodified — propulsion is untouched. Replace the front section with a custom-fabricated fixture carrying the Pico 2 W, PMW3360, ICM-42688-P, and IR reflectance lap sensor (§3, §6), plus the guide flag.

Requirements this imposes on the fixture, beyond sensor mounting:

- **Preserve the guide flag's pivot mount.** It self-centers in the slot on a small pivot peg in the stock chassis; that compliance is part of how the car tracks corners. Rigidly fixing it instead of carrying the pivot over risks poor cornering or the flag popping out of the slot.
- **Reuse the guide flag's pickup braids as the rail power tap.** They're already the existing power path into the car — splice the buck-boost regulator's input into the same two wires (or a shared node) feeding the motor, rather than adding a separate tap. Cutting the chassis severs the existing wire run regardless, so this re-routing has to happen either way.
- **Bridge the cut structurally, not just electrically.** Removing the scored section removes the plastic that transmitted chassis stiffness between front and rear — the fixture needs to mechanically splice the two halves back into one rigid chassis, not just sit alongside the rear section.

**Front support: sled/skid (selected over small idler wheels).** The stock front wheels are non-driven idlers to begin with (the slot does the steering), so removing them is low-risk, and skid/floating front ends are already a precedented technique in the hobby (e.g. F1-style slot chassis). The decisive reason for this project specifically: a skid lets the optical sensor's standoff height be referenced directly off the same molded contact surface that sets ride height, rather than being at the mercy of separate bearing/axle/suspension play — one less independent source of variance in the one dimension (sensor-to-track distance) this whole design most needs to hold constant.

Design constraints that follow from choosing a skid:

- **Two contact points (or one wide skid), not a single central point**, spaced at roughly the stock front track width (77.83mm outside-to-outside) — a single-point skid can rock side-to-side, and that rocking would inject false roll into both the optical flow reading and the IMU.
- **Rounded/ski-tip leading edge**, not a flat/sharp one — track-piece seams are exactly where small height discontinuities occur, and a flat skid edge is more likely to catch on a proud seam than a rounded one is to bridge it.
- **Low-friction, wear-resistant skid material** (e.g. PTFE tape or a bonded Delrin/POM insert) — sliding friction is higher than rolling friction, and unlike a wheel, a worn skid directly lowers ride height (and therefore sensor focus distance) over time.
- **Reference the sensor mount to the skid, not to an independent chassis datum** — mount the PMW3360's standoff at a fixed distance from the skid's own contact plane on the same molded part, so the two stay coupled even if the skid wears.

**Open risk to validate once a prototype exists (not blocking the design, just untested):** sliding stick-slip friction can produce higher-frequency vibration than a rolling contact would, which could show up as noise in the optical flow and accelerometer readings. If that turns out to be a real problem in practice, the mitigation is a material/geometry change to the skid tip, not a redesign of the fusion approach.

**Second guide, added: a dummy pin behind the PMW3360, bracketing it between two slot-engaged points.** The stock front guide flag keeps its existing role unchanged (slot engagement + power pickup via its braids). The problem it doesn't solve on its own: with only one slot-constrained point, the fixture's orientation between there and the rear splice is otherwise set by whatever the stock rear wheels happen to be doing on the open track surface — friction- and grip-dependent, and prone to skid/slip exactly where it matters most, through the tight corners. None of §2's fusion model or `sim/simulate_track_run.py`'s error simulation accounts for that; both assume the guide-flag position (hence the sensor, via the lever-arm correction) tracks the slot centerline directly. A second, independently-pivoting pin — hard plastic, no wiring, purely mechanical — placed behind the PMW3360 makes that assumption true by construction for the sensor-carrying section: its orientation is then set entirely by two points of slot geometry, not by rear-tire grip.

Sizing the spacing between the two guides means checking against the track's *actual* tightest curve, not an assumed one — computed directly from `tmp/bolton-track.svg` across all four lanes (not just the "yellow" lane used elsewhere in this project's simulation work), the minimum radius is **221.1mm on the red lane**, tighter than yellow's 370mm and lime/blue's ~260-270mm. Given a slot as narrow as 2.5mm and a 1mm-wide hardbody-style pin for the new guide, available clearance is (2.5 − 1)/2 = **0.75mm per side**. For two independently-pivoting points rigidly separated by distance `L`, both riding the same curve of radius `R`, the geometric mismatch that would force one against its slot wall is `L³/(24R²)` (the gap between the rigid chord length and the true arc length between the corresponding points on the curve) — at the fixture's current ~49.5mm guide spacing (`cad/fixture.scad`'s `guide_spacing`) against the worst-case 221.1mm radius, that's **≈0.10mm, under 14% of the 0.75mm budget** — comfortable margin, with headroom to spare (the mismatch doesn't reach the full budget until spacing approaches ~96mm, well beyond anything this fixture needs). The other quantity this could be confused with — sagitta, `L²/(8R)` — is larger (≈2.4mm at this spacing) but doesn't apply here: it's the deviation a *rigid, non-pivoting* structural member spanning the two points would see, and nothing in this design has such a member reaching into the slot — only the two independently-pivoting pin tips do.

**This only holds if the second guide pivots freely**, the same requirement §7 already states for the front one — a rigidly-fixed (non-pivoting) second pin would face a real angular mismatch against the local slot tangent (≈8.4° at this spacing and the worst-case radius) and would genuinely bind. A loose, rotating pin in its mount (not glued, matching the front guide's own "MUST preserve the free pivot" rule) absorbs that the same way real single-guide slot cars already absorb a changing slip angle through every corner.

`cad/fixture.scad`'s `rear_guide_mount()` implements this, positioned in the ~2.3mm-wide gap that's actually available between `rear_splice()` and `pico_mount()`'s board edge (checked by explicit bounding-box comparison during layout, not by eye — the first placement attempt used a wider boss and left only a 0.3mm window, tight enough to be worth flagging as a lesson for future changes to this area of the layout).

### CAD model

`cad/fixture.scad` is the parametric OpenSCAD model implementing this section: rear splice tab, a deck that flares from the 55mm spine width out to the 77.83mm front track width (so the skids actually land on structure instead of floating past a narrow deck's edge), Pico 2 W + ICM-42688-P mounted on top, PMW3360 + IR reflectance sensor hanging below near the guide-flag pivot, the two ski-tip skid pads, and the second (dummy) guide pin behind the PMW3360 (above). All donor-chassis dimensions in the file are now from calipers (this section's opening paragraph); the component footprints (Pico/PMW3360/ICM-42688-P/IR module exact sizes) are still typical/placeholder values pending the actual parts bought, and `rear_splice()` is still a placeholder lap joint pending the real spine cross-section/rib profile — not print-ready on either count yet.

Render previews with e.g. `openscad --autocenter --viewall -o preview.png cad/fixture.scad`; the file's `echo()` statements print the computed total length, the resulting lever-arm `r` (§2), and flag if a sensor standoff or the Pico's mounting zone comes out negative/too tight.

## 8. Open items before build

- Measure/fix the sensor-to-pivot offset **r** once the fixture is machined.
- Apply the start/finish marker to the track and record its true (X₀, Y₀) as the mapping origin. Start with a 40mm-wide tape strip (§6's sizing rule) and re-check it once the real loop period and approach speed are measured.
- Measure `main.py`'s actual achieved loop period on real hardware (it's unthrottled — no `sleep()` — so this is currently unknown, not just uncalibrated) and re-run §6's tape-width sizing formula against the real number.
- Measure real logic-rail current draw on the built fixture and size the supercap (§4) from it rather than the rough estimate.
- Source PMW3360, ICM-42688-P, IR reflectance sensor, Pico 2 W, and buck-boost regulator/supercap parts and confirm they all physically fit the 1/24 fixture footprint.
- Confirm the real Pico 2 W board's GPIO pin numbering matches the RP2040 `RaspberryPi_Pico` library symbol used in the schematic (§3 addendum) and now hard-coded in `main.py`.
- Run `main.py` on real hardware for the first time and work through its documented calibration steps: `LAP_THRESHOLD` against the actual IR marker, the gyro-sign/optical-axis sanity checks, and confirm `calibrate_gyro_bias()`'s stillness threshold (`GYRO_CAL_MAX_ACCEL_STD_G`) against the real accelerometer's noise floor (§6).
- Calibrate the PMW3360's actual CPI-to-distance conversion by rolling a known distance, rather than trusting the nominal CPI setting in `pmw3360.py`.
- Get the actual PMW3360, ICM-42688-P, and IR reflectance breakout boards and replace `cad/fixture.scad`'s typical/placeholder footprint dimensions with real ones (donor-chassis dimensions are now measured — this is the remaining unverified category).
- Redesign `rear_splice()` in the CAD model as a real tongue-and-groove or screwed lap joint once the stock spine stub's cross-section (thickness, ribs) is measured — 3.6mm is the flat thickness at the cut face, not the full joint profile.
- Double-check the Pico 2 W's real board+header footprint (not just the bare PCB outline) against the ~2mm per-side clearance the rotated mount currently has in the 55mm-wide spine section — tight enough to matter.
- Prototype the skid and check for stick-slip vibration in practice (§7's open risk) before committing to a final skid material/geometry.
- Print/fabricate the front fixture from the finalized CAD model.
- Design the mechanical splice + wiring re-route across the cut (§7) between the new front fixture and the stock rear motor/drive section.
- Pick an actual buck-boost regulator part (§4 says "TPS63070-class" illustratively; `electronics/electronics.kicad_sch` represents it as a generic labeled connector) and, once chosen, swap in its real symbol/footprint.
- Re-size R1 and C1 together once that regulator's real current limit is known (§4) — R1=4.7Ω/C1=1F is provisional, picked before either the regulator or the cap was final.
- Same for the PMW3360/ICM-42688-P/IR reflectance breakout boards in the schematic — generic connectors for now, real symbols once specific boards are bought (tie this to the CAD footprint task above).
- Add a 10k pull-up from CS to 3V3 on the PMW3360 net once its real symbol replaces the generic connector, and confirm the sourced breakout's power pins (does it expose VDD/VDDIO/VDDPIX separately, or hide them behind an onboard 1.8V regulator?) — §3 addendum, prompted by cross-checking Ploopy's bare-chip reference schematic.
- Determine the real Bolton track's actual net-turns value for `tools/closed_loop_correct.py --net-turns` by inspecting the built track's driven lane (§6) — the simulation used 0.0, computed from `tmp/bolton-track.svg`'s geometry, but that plan may not exactly match what gets built/driven in practice.
- Improve `tools/closed_loop_correct.py --average-out` to align each lap's orientation before averaging (it currently doesn't, which measurably inflated its reported length relative to the simple per-lap mean in testing — §6).
- Build a lane-combining tool (§9) — currently a documented manual procedure, not automated: no script yet translates several per-lane vector outputs into one shared-frame track file.
- Get real-hardware drift numbers from Stage 11 and compare them against §10's simulated gyro-quality comparison before deciding whether the stock ICM-42688-P is good enough or an IMU upgrade is worth its size/cost/power cost.
- Confirm the real track's narrowest slot width (§7 used 2.5mm as given, not yet measured) and re-check the second guide's clearance margin once it is.
- Build and test the second guide pin + its pivot (§7) — confirm a loose, hard-plastic pin actually pivots freely enough in practice, and re-measure `r_worst_mm` (currently the Bolton SVG plan's value, §9's same caveat) against whatever track it's actually built on.

## 9. Design rationale: mapping every lane into one accurate vector track map

This section is the answer to "how does this design actually solve the stated goal (§1) end to end" — it ties §2–§8's individual decisions together into why the resulting output is a usable vector representation of a whole multi-lane track, not just a rough sketch of one lane.

**Why this has to be N independent runs, not one.** The sensor package is mechanically committed to whatever slot the guide pin is sitting in (§7) — it has no way to see or measure any lane but the one it's currently driving. A track with N lanes therefore needs N separate recording sessions (BRINGUP.md Stage 11, once per lane), full stop. There's no clever fusion trick that gets around this; it's a direct consequence of the guide-pin-constrained sensing approach chosen in §2, and worth stating plainly since it shapes everything below: the design goal isn't "one magic run that maps the whole track," it's "make each single-lane run accurate and cheap enough to repeat N times without N times the effort."

**What one run actually produces.** Per lane, the pipeline in §2 and §6 — optical-flow translation, lever-arm-corrected and rotated by fused heading, reset at a physical tape marker, corrected once per lap using the closed-loop constraint that a lap's net turning is a known geometric quantity (§6), then averaged across several laps to reduce the residual random-noise component (§6, `tools/closed_loop_correct.py --average-out`) — produces a sequence of (x, y) points in millimeters, plus a measured length in meters. That sequence *is* a vector path in the literal sense: it's the same polyline representation `tmp/bolton-track.svg` itself uses (straight segments approximating a smooth curve), so it's directly usable by the same class of tools (import into a vector drawing/CAD program, overlay on a floor plan, or just view it via `tools/plot_track_csv.py`) without any format translation.

**Getting from N accurate single-lane paths to one accurate multi-lane map.** This is the part that needs a small amount of information from outside the onboard sensors, deliberately, rather than trying to make the car sensors solve a problem they're not positioned to solve:

- **A shared start reference, for free.** Placing one physical tape strip across *all* lanes at the same cross-section (rather than a separate tape per lane) means every lane's run is anchored to the same physical location and crossing event — `BRINGUP.md`'s recommendation to place the tape on a straight or gentle curve (originally justified there purely by tape-width sizing, §6) does double duty here: on a straight, all lanes run parallel, so the heading each run's `main.py` locks in at power-up (car sitting still, pointed forward in its own lane) is *also* approximately shared across lane-runs, not just the crossing point.
- **One small measurement, done once, not per run.** With a common crossing point and an approximately common heading reference, the only thing separating one lane's local frame from another's is the lateral offset between them *at that one cross-section* — a distance a caliper or ruler measures directly, standing at the line, once per lane pair (or once per lane relative to a chosen reference lane). This is deliberately kept as a human, out-of-band measurement rather than something the onboard sensors are asked to infer: it's a single small number per lane, trivial to get right, versus asking a guide-pin-constrained car to somehow perceive a lane it isn't in.
- **Combining:** translate each lane's vector path by its measured lateral offset (perpendicular to the shared start heading), and all N paths land in one common coordinate frame — a complete vector map of the track, every lane included, each with its own independently-measured length.

**Status:** the per-lane half of this (an accurate vector path for one lane) is implemented and validated in simulation (§6, `sim/`, `tools/`). The combining half (translating N per-lane files by their measured offsets into one shared-frame output) is currently a manual procedure as described above, not yet a script — see §8's open item. It doesn't need new sensing or firmware work, only a small offline tool once real multi-lane data exists to combine.

## 10. Would a better/more expensive gyro reduce drift?

Yes, but the honest answer has two parts worth separating, because they point at different fixes.

**Which error component actually matters here.** A gyro's heading error has two largely independent pieces: *angle random walk* (statistical noise, integrates as √N over time) and *bias instability* (the zero-rate offset wandering slowly, e.g. with self-heating, on a timescale of seconds to minutes — not a single fixed number the way §6's at-rest calibration treats it). This distinction matters because of what §6's two software mitigations can and can't reach:

- **Multi-lap averaging** (`tools/closed_loop_correct.py --average-out`) reduces error that's *independent* from lap to lap — mainly the random-walk-noise component.
- **Closed-loop per-lap correction** removes whatever *constant* bias offset best explains one lap's total measured turning — but if the real bias wanders meaningfully *within* a single ~12s lap (or drifts similarly across all laps of one short recording session, e.g. from the electronics warming up), neither technique touches that residual. A better gyro's main real benefit here is a lower bias-instability spec (measured in °/hr) — that's the number to look for, not the more commonly advertised noise-density figure, which the averaging step already substantially addresses in software at no part cost.

**Quantified, not just asserted:** re-running `sim/simulate_track_run.py` with gyro noise and bias reduced 5x and 10x respectively (representative of a meaningfully better MEMS part) dropped the simulated closing error from 1098mm to 805mm on the same 5-lap run — a real, meaningful reduction in path-shape accuracy. Notably, it did *not* change the reported lap-length spread (32mm either way): lap length is dominated by the optical sensor's own forward-distance measurement, which the gyro barely touches, while gyro quality mainly affects path *shape and position* fidelity, not the total-distance figure highlighted in §6/`BRINGUP.md`. The 805mm floor is itself partly an artifact of how this project's simulator synthesizes its test gyro data (§6's `HEADING_WINDOW_MM` caveat) rather than a true physical limit — real hardware with a better gyro would likely show a larger relative improvement than this simulation does.

**Whether it's worth it for this project specifically:** a gyro with materially better bias instability (the tactical-grade/industrial IMU tier, not just a nicer consumer MEMS part) is real, but usually comes with a size, weight, power, and cost jump that works against §4's power story and §7's 1/24-scale fixture constraints — the ICM-42688-P was chosen in §3 partly *because* it fits that envelope. The practical recommendation: get real drift numbers from Stage 11 first. The software techniques already built (calibration, closed-loop correction, averaging) are free in hardware terms and get a meaningful fraction of the achievable improvement; only reach for a different IMU part if real-hardware drift, after all of that, still isn't good enough for the map's intended use — and if so, spec-check bias instability specifically, not just noise density.

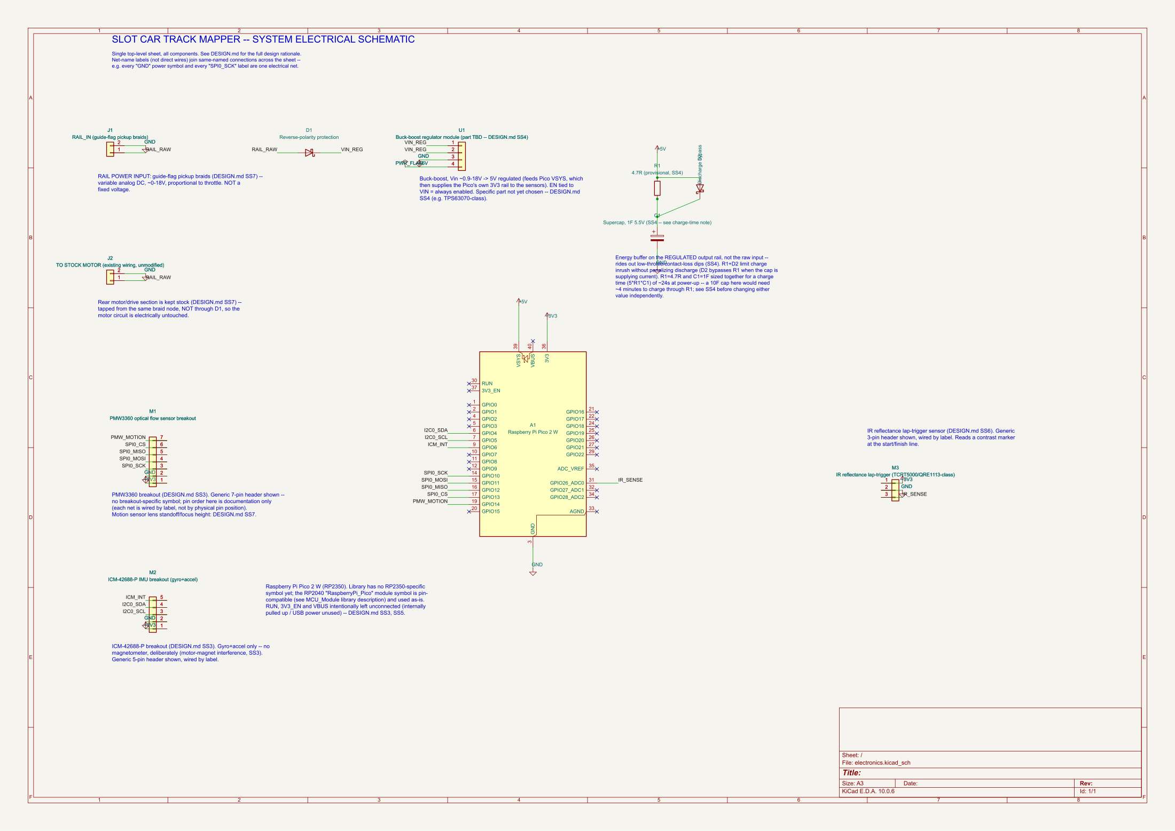
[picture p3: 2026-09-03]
electronics/preview.png

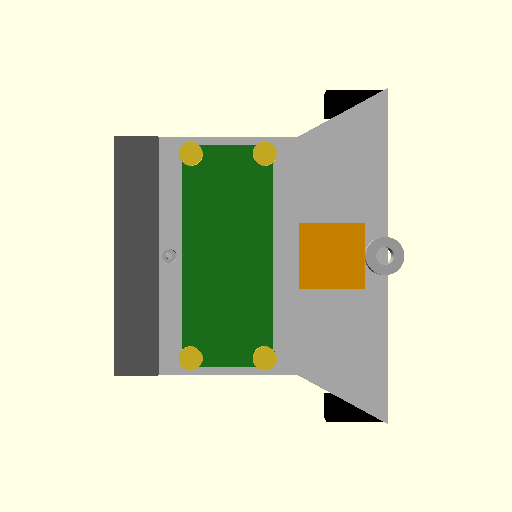
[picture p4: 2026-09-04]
cad/preview_side.png

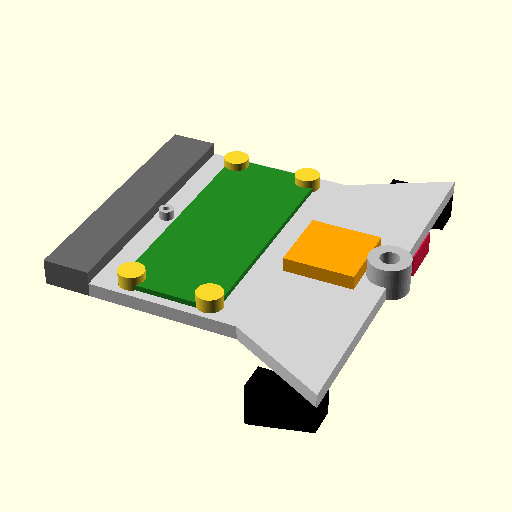
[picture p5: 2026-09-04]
cad/preview_iso.png

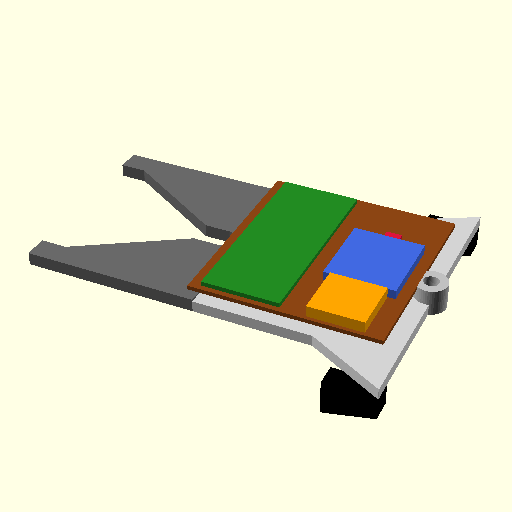
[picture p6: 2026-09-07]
cad/preview.png

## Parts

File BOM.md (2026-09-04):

# Bill of Materials

Parts for **one complete fixture/car** — per `DESIGN.md` §9, mapping every lane of a multi-lane track uses this same physical device driven once per lane, not one device per lane, so this list doesn't scale with lane count.

Status column: **confirmed** = a measured dimension or a part this project has committed to; **TBD** = a generic/illustrative stand-in in the schematic or CAD, still needing a specific part picked (tracked in `DESIGN.md` §8's open items — this file is the shopping list, §8 is why each TBD is still open).

## Electronics

| Qty | Part | Spec / notes | Status | Ref |
|---|---|---|---|---|
| 1 | Raspberry Pi Pico 2 W | RP2350, CYW43439 WiFi | Confirmed | `DESIGN.md` §3, schematic `A1` |
| 1 | PMW3360 optical flow sensor breakout | SPI, needs real SROM firmware sourced separately (`pmw3360.py`'s placeholder) | Confirmed part / firmware TBD | `DESIGN.md` §3, schematic `M1` |
| 1 | ICM-42688-P IMU breakout | I2C, gyro+accel only — no magnetometer variant needed/wanted | Confirmed | `DESIGN.md` §3, schematic `M2` |
| 1 | IR reflectance sensor module | TCRT5000/QRE1113-class, active-IR, analog or digital output to `IR_ADC_PIN` (GPIO26/ADC0) | Confirmed type, specific board TBD | `DESIGN.md` §6, schematic `M3` |
| 1 | Buck-boost regulator module | Input ~0.9–18V → 5V out; "TPS63070-class" is illustrative only | **TBD** | `DESIGN.md` §4, schematic `U1` |
| 1 | Supercapacitor | 1F, 5.5V (schematic value) — re-size once the regulator's real current limit is known (`DESIGN.md` §4) | **TBD** (value provisional) | schematic `C1` |
| 2 | Schottky diode | Small-signal, low-Vf — D1 = reverse-polarity protection on the rail input, D2 = supercap charge-inrush bypass | Confirmed function, specific part TBD | `DESIGN.md` §4, schematic `D1`/`D2` |
| 1 | Resistor, R1 | 4.7Ω provisional — inrush-limiting for the supercap; re-size with the regulator (`DESIGN.md` §4) | **TBD** (value provisional) | schematic `R1` |
| ~0.3m | Hookup wire, small gauge (stranded) | Power tap from the guide-flag braids into `U1`'s input, plus any point-to-point wiring from the breakouts to the Pico's SPI0/I2C0/GPIO pins (`DESIGN.md` §3 pin table) | Confirmed need, gauge/length TBD until layout is final | — |
| 1 | Micro-USB cable | Programming + bench power for the Pico 2 W (keeps the original Pico's connector, not USB-C) | Confirmed | `BRINGUP.md` Stage 0/1 |

## Mechanical

| Qty | Part | Spec / notes | Status | Ref |
|---|---|---|---|---|
| 1 | Donor chassis | Scaleauto Slotcar Chassis 1:24 Analog HS-124 Universal Complete Chassis, plastic, sidewinder, variable wheelbase 96–114mm | Confirmed | `DESIGN.md` §7 |
| 1 | 3D-printed fixture body | From `cad/fixture.scad` — material not yet decided; PLA or PETG are the typical candidates for this fit and load | **TBD** (material) | `DESIGN.md` §7 |
| ~50mm | Rod stock, ~1.2mm diameter | Second (dummy) guide pin — hard plastic (styrene) or brass rod, cut to length, free-pivoting in `rear_guide_mount()` | Confirmed spec, stock source TBD | `DESIGN.md` §7 |
| 2 | Skid pad insert/coating | PTFE tape or a bonded Delrin/POM insert on each of the two ski-tip skid pads (`cad/fixture.scad`'s `skid_pad()`) | **TBD** (material choice) | `DESIGN.md` §7 |
| 4 | M2.5 standoff + screw (or equivalent) | Pico 2 W mounting, matching `pico_hole_d = 2.5mm` in the CAD | Confirmed hole size, hardware TBD | `cad/fixture.scad` |
| — | Splice joint fastener/adhesive (screws or epoxy) | Bridges the cut between the new fixture and the stock rear motor/drive section — `rear_splice()` is still a placeholder lap joint pending the real spine cross-section/rib profile | **TBD** | `DESIGN.md` §7 |

## Consumables

| Qty | Part | Spec / notes | Status | Ref |
|---|---|---|---|---|
| 1 strip | Reflective tape | ~40mm wide (sizing rule, `DESIGN.md` §6), laid across *all* lanes at one cross-section (`DESIGN.md` §9) — enough length to span the full track width plus lane-marker spacing | Confirmed width, brand/material TBD | `DESIGN.md` §6, `BRINGUP.md` Stage 11 |

## Tools (not consumed — bring-up only, `BRINGUP.md` Stage 0)

- Multimeter (essential)
- Breadboard + jumper wires
- Bench-adjustable DC supply (optional — the analog track controller substitutes, since it's already a variable 0–18V DC source)
- Calipers (for the second-guide clearance check, `DESIGN.md` §7, and any future dimension re-checks against real parts)

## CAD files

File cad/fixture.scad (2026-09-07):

// ======================================================================
// Slot Car Track Mapper — Front Sensor Fixture (parametric, first pass)
//
// Donor chassis: Scaleauto HS-124, plastic, sidewinder, variable
// wheelbase 96-114mm. See ../DESIGN.md §7 for the full mechanical plan
// and reasoning behind every decision referenced below.
//
// Cut the donor chassis at its molded score line ("the V") in front of
// the motor box. The rear motor/drive section is kept stock and is NOT
// modeled here. This part REPLACES the front section: it splices onto
// the rear stub, carries the guide flag and a shared strip-board PCB
// (Pico 2 W, PMW3360, ICM-42688-P, and the IR reflectance lap sensor all
// on one board — see shared_pcb()), and rides on a two-point skid
// instead of the stock front wheels.
//
// This deck IS the PMW3360 datasheet's (tmp/C20612443.pdf) "Customer
// Supplied Base Plate with Recommended Opening" (Fig. 8) — pmw_lens_pocket()
// below implements that opening directly. The strip board is the
// datasheet's "Customer Supplied PCB" (Fig. 5): one hand-cut board wired
// point-to-point along its copper strips, not four separate breakouts.
//
// Units: mm. X=0 at the rear cut face, +X toward the front/guide flag.
// Y=0 on the car's centerline. Z=0 at the track surface.
//
// ---------------------------------------------------------------------
// STATUS: fourth pass. All donor-chassis dimensions below are now from
// calipers on the real part (not photo estimates), including the
// front-of-motor carrier profile (tmp/chassis-front-of-motor.jpeg) that
// the fixture's rear edge now mirrors — see carrier_interface() below,
// which replaces the old flat-cube rear_splice() placeholder. The second
// (rear) guide pin no longer has fixture-side geometry: it uses a small
// pre-existing hole near the carrier's tab tip instead of a molded boss.
// Electronics are consolidated onto one shared strip board (shared_pcb())
// rather than mounted individually. Still NOT print-ready: the ICM-42688-P
// footprint is still a typical/placeholder value, the PMW3360 lens pocket
// is a simplified (non-tapered) approximation of Fig. 8's real "D" shape,
// and the IR sensor's exact part (QRE1113-class assumed, see the
// component footprints below) still needs confirming.
// ======================================================================

// ---- MEASURED on the physical chassis (trust these) -------------------
wheelbase           = 114.25;
front_track_width   = 77.83;  // outside-to-outside, stock front wheels
rear_track_width    = 80.72;  // outside-to-outside, stock rear wheels (kept stock — informational only)
spine_width         = 55.0;   // width of the main chassis spine at the cut
cut_to_front_axle   = 47.0;   // OLD flat-cut estimate to the (former) front axle centerline —
                               // superseded by the carrier_* profile below now that the mating edge
                               // follows the motor carrier's contour instead of a straight cut; kept
                               // for reference only, no longer feeds total_length (see below).
front_axle_to_guide = 18.0;   // front axle centerline to guide-flag tip
spine_thickness     = 3.6;    // stock spine plastic thickness at the cut face
guide_peg_dia       = 3.8;    // stock guide-flag pivot peg diameter
guide_peg_depth     = 7.0;    // stock guide-flag pivot peg engagement depth

// ---- MEASURED: front-of-motor carrier profile (tmp/chassis-front-of-motor.jpeg) ----
// The kept rear section's front face isn't a flat cut — it's this raised
// (carrier_h tall) wedge-and-tab boss molded into the chassis, sitting in
// front of the motor box. The fixture doesn't butt a flat face against a
// flat cut; its leading edge is notched to MIRROR this exact outline so
// the two halves key together and self-align. There's also a small
// pre-existing hole near the tab tip that the second (rear) guide pin
// uses directly — no fixture-side boss needed for it, unlike the earlier
// design's rear_guide_mount() (removed).
carrier_base_w      = 41.45;  // width at the base (widest point, nearest the motor)
carrier_base_len    = 7;      // length of the two parallel sides before the taper starts
carrier_taper_len   = 28.5;   // length of the two tapering sides, base width down to the tab width
carrier_tab_w       = 6.25;   // tab width
carrier_tab_len     = 10;     // tab length, taper apex to the top of the radiused tab tip
carrier_h           = 3.5;    // height of the carrier boss above the surrounding chassis floor —
                               // also the fixture's thickness at the mating edge, so both faces meet flush
carrier_total_len   = carrier_base_len + carrier_taper_len + carrier_tab_len;  // 45.5mm, base to tab tip
carrier_clearance   = 0.3;    // per-side clearance so the notch actually seats over the real part
carrier_wall        = 2;      // solid plastic left beyond the tab tip, for edge strength
carrier_zone_len    = carrier_total_len + carrier_wall;  // 47.5mm — how far forward the interface plate extends

total_length = carrier_zone_len + 55;
// NOTE: total_length used to be cut_to_front_axle + front_axle_to_guide (65mm) with a 10mm placeholder
// splice (rear_splice()). Now that the rear interface is the real carrier_zone_len (47.5mm) instead of
// that 10mm placeholder, the fixture is elongated by the same amount (+37.5mm) so the Pico/sensor/
// guide-flag zone ahead of it keeps the same 55mm of usable length it had before.

// Lever arm from the guide-pin pivot (DESIGN.md §2) to wherever the
// optical sensor actually ends up — feed this into the fusion loop's
// lever-arm correction once it's finalized here.
pmw_x = total_length - front_axle_to_guide;
lever_arm_r = total_length - pmw_x;

// ---- Component footprints — VERIFY against the specific parts bought --
pico_l = 51; pico_w = 21;                                  // Pico 2 W board outline
pico_hole_dx = 47; pico_hole_dy = 17; pico_hole_d = 2.5;    // mount-hole pattern (+ clearance)

// PMW3360DM-T2QU + LM19-LSI lens — MEASURED from the real datasheet
// (tmp/C20612443.pdf, PMW3360 Product Datasheet Rev 1.50), not typical
// guesses. Fig. 4 ("Assembly drawing... distance from lens reference
// plane to tracking surface") and Fig. 8 ("Recommended Base Plate
// Opening") describe exactly the joint our deck needs to form — the
// datasheet's "Base Plate" IS our fixture deck (see header note above).
pmw_l = 19.00; pmw_w = 21.35;               // Fig. 8 recommended base-plate opening keepout (X/Y — axis
                                              // assignment is a reasonable-not-yet-verified read of the
                                              // drawing; both fit comfortably in our available space either way)
pmw_opening_r    = 7.05;                     // Fig. 8 outer opening corner radius
pmw_hole_w       = 10.97; pmw_hole_l = 10.97; // Fig. 8 Detail F inner pass-through hole (approximated as a
                                              // rounded square — the real opening is a "D" shape with a
                                              // 69.6° taper wall; refine once the lens is in hand)
pmw_hole_r       = 2.00;                     // Fig. 8 Detail F inner hole max corner radius
pmw_base_plate_t = 2.40;                     // Fig. 8 recommended base-plate thickness at the opening —
                                              // the deck must be thinned to exactly this locally, not deck_t,
                                              // or the lens flange sits proud and focus distance grows
pmw_focus_height = 2.40;                     // Fig. 4 "Bottom of Lens Flange to Navigation Surface (Z)" —
                                              // confirms the old "typical" 2.4mm guess was exactly right
pmw_pcb_standoff = 2.90;                     // Fig. 4 "Gap between PCB & Base Plate" — the shared strip
                                              // board (below) mounts this far above the deck's top surface
pmw_chip_h       = 2.41;                     // Fig. 4 "Top of Chip Package to Navigation Surface" (9.81) minus
                                              // "Top of PCB to Navigation Surface" (7.40) — visual height only

icm_l = 15; icm_w = 15; icm_t = 3;                         // ICM-42688-P breakout, typical
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

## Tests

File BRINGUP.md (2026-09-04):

# Bring-Up Plan: Slot Car Track Mapper

Status: nothing in this build has touched real hardware yet — `DESIGN.md` is the rationale, `cad/`, `electronics/`, and the firmware (`main.py`, `pmw3360.py`, `icm42688.py`) are all first-pass artifacts with known placeholders (SROM firmware, `LAP_THRESHOLD`, several CAD dimensions). This plan sequences validation so each stage retires a specific set of unknowns before the next stage depends on them — and so the one irreversible step (cutting the donor chassis, §7) happens last, after everything it depends on has already been proven on the bench.

**Ground rule:** don't proceed past a stage's pass criteria on a "probably fine" — the whole point of staging is that a failure here is cheap to diagnose (one new variable) and expensive to diagnose three stages later (five new variables at once).

## Stage 0 — Prerequisites

**Parts for the electronics stages below (Stages 1–6):** Pico 2 W, PMW3360 breakout, ICM-42688-P breakout, IR reflectance module (TCRT5000/QRE1113-class), buck-boost regulator module, supercap, Schottky diodes ×2, resistor for R1, breadboard + jumper wires, USB cable — `BOM.md` is the complete, authoritative parts list (electronics, mechanical, consumables, with sourcing status for each) covering the whole build, including the mechanical parts (chassis, fixture material, guide pins, skid material, tape) not needed until Stages 7+.

**Tools:** multimeter (essential). A bench-adjustable DC supply is nice to have for Stage 2, but not required — the analog track controller you already have *is* a variable 0–18V DC source (that's literally its job), so it can double as one with the car disconnected.

**Software:** MicroPython firmware flashed onto the Pico 2 W, Thonny or `mpremote` for REPL access and file transfer.

**Before Stage 3 specifically:** source the real PMW3360 SROM firmware (see `pmw3360.py`'s docstring and `DESIGN.md` §3/§6 — the placeholder will not track). The known-good technique is the same one `a6_binary.py` already used for the ADNS-9800: take a verified open-source driver's firmware header (e.g. SunjunKim's PMW3360 Arduino library) and convert it to a Python byte array. Do this before Stage 3, not during it.

---

## Stage 1 — Pico 2 W solo bring-up

**Goal:** confirm the board and toolchain work before anything else depends on them.

**Procedure:** flash MicroPython, connect via Thonny/`mpremote`, confirm the REPL banner shows the expected MicroPython/board version. Run a trivial `Pin` toggle on the onboard LED.

**Pass:** REPL connects reliably; LED blinks.

**If it fails:** don't touch sensors yet — this is a flashing/driver/cable problem, isolate it here.

---

## Stage 2 — Power subsystem bench validation (independent of firmware — can run in parallel with Stages 3–6)

**Goal:** validate the regulator + R1/D2/C1 sub-circuit (`electronics/electronics.kicad_sch`, `DESIGN.md` §4) against a *real* variable input, and get the real numbers needed to close out that section's open items.

**Setup:** regulator + D1 + R1 + D2 + C1 built on breadboard per the schematic, fed from the track controller (car disconnected) so input voltage sweeps the real 0–18V-ish range. Load the output with the Pico (running, drawing its normal current) rather than a dummy resistor — real current draw is what actually matters here.

**Procedure and what to record:**
1. Sweep the controller trigger through its range; multimeter on regulator output. Record output voltage at several trigger positions, and find the trigger position where regulation first fails (input too low).
2. Measure the regulator's actual current limit if its datasheet doesn't already state one you trust (slowly increase load, or check the datasheet) — this is the number `DESIGN.md` §4 flags as missing for properly sizing R1.
3. Time the supercap charging from empty to steady-state at full trigger. Compare against the ~24s prediction (R1=4.7Ω, C1=1F). If it's very different, R1 or C1 need updating together, not independently (§4 explains why).
4. With the cap charged and the Pico running, cut input power and time how long output stays above ~3V. Compare against the ride-through estimate in §4.
5. Briefly test reverse polarity at the input (low current, be ready to disconnect) and confirm D1 protects the regulator.

**Pass:** regulator holds ~5V down to a throttle position you're comfortable calling "the floor"; charge and ride-through times are in the right ballpark or you've recorded real numbers to update `DESIGN.md`/the schematic with; reverse polarity doesn't damage anything.

**If it fails:** this is bench-testable in complete isolation from every other stage — fix it here, not after it's built into the fixture.

---

## Stage 3 — PMW3360 solo bring-up (breadboard)

**Goal:** get real SROM firmware in and confirm the sensor actually tracks, before it's anywhere near the car.

**Setup:** PMW3360 breakout wired to the Pico exactly per the schematic (GPIO10-13 SPI0, GPIO14 motion interrupt — currently unused/polled), powered from USB for now (not the regulator yet).

**Procedure:**
1. Before touching SROM: read `PRODUCT_ID` (register 0x00) over SPI. This is a fixed silicon value and should read `0x42` regardless of SROM state — if it doesn't, it's a wiring/SPI problem, not an SROM problem. Isolate that distinction here.
2. Drop the real SROM firmware into `pmw3360.py` (Stage 0). Run `PMW3360.begin()`; confirm it doesn't raise, and that the SROM ID it returns is non-zero.
3. Slide the sensor by hand over a real surface and poll `read_motion()`. Confirm non-zero, sensible-sign `(dx, dy)` that match the direction you actually moved it.
4. Calibrate CPI: move the sensor a measured distance (e.g. 100mm along a ruler) and compare accumulated counts against the nominal CPI setting in `pmw3360.py`. Adjust if the real conversion factor is off.

**Pass:** motion counts track real hand movement in the correct direction and roughly the correct magnitude.

**If it fails after real SROM is in:** check the axis/sign assumption before assuming the driver is broken — a mirrored or rotated sensor lens will report axes that don't match intuition without being "wrong."

---

## Stage 4 — ICM-42688-P solo bring-up (breadboard)

**Goal:** confirm the IMU driver and get the real gyro sign, before the fusion loop depends on it.

**Setup:** breakout wired per schematic (GPIO4/5 I2C0, GPIO6 interrupt — currently unused/polled), USB power.

**Procedure:**
1. `ICM42688.begin()` — confirm `WHO_AM_I` reads `0x47`.
2. At rest, read `read_accel_g()` — confirm one axis reads ~1g (gravity) and the other two read ~0g, consistent with however the breakout happens to be lying flat on the bench.
3. Rotate the board by hand around what will be the vertical (yaw) axis once mounted; watch `read_gyro_dps()`'s Z value. Confirm it's near-zero at rest and changes sign consistently with rotation direction.

**Pass:** `WHO_AM_I` correct; gyro Z responds to rotation with a sign you've now written down (this is the "flip the sign in `main.py` if a by-hand test shows it backwards" check the code's docstring flags).

**If it fails:** I2C address or wiring first (0x68 is assumed in `icm42688.py` — some breakouts strap it to 0x69).

---

## Stage 5 — IR reflectance sensor solo bring-up + `LAP_THRESHOLD` calibration

**Goal:** replace the guessed `LAP_THRESHOLD` with a real number from the actual marker material.

**Setup:** module wired to GPIO26 (ADC0) + power, USB power.

**Procedure:** print raw `ADC(26).read_u16()` continuously while passing the sensor over (a) bare track surface and (b) the actual marker tape/material you intend to use, at the real intended standoff height (§7's fixture geometry, once known). Record both values.

**Pass:** a clear, repeatable gap between the two readings. Set `LAP_THRESHOLD` in `main.py` roughly at the midpoint, with margin on both sides.

**If there's no clear gap:** the marker material/contrast needs to change before this sensor will work reliably — don't paper over it with a marginal threshold.

---

## Stage 6 — Combined electronics bring-up (still on the bench, not on the car)

**Goal:** all three sensors + Pico together, running the real `main.py` fusion loop, before any mechanical integration.

**Setup:** PMW3360 + ICM-42688-P + IR sensor all wired simultaneously per the schematic, USB power (Stage 2's power subsystem can be integrated here too if it's already validated, but isn't required to prove the firmware logic).

**Procedure:** run `main.py` as-is. Since there's no track yet, do a "hand-driven dry run": manually slide and rotate the whole breadboard assembly on a tabletop, roughly simulating a lap (including something crossing the IR sensor's marker test setup from Stage 5 to trigger a lap reset). Watch the printed lap messages and the resulting `track_log.csv`.

**Pass:** `(x, y, θ)` move in directions consistent with how you actually moved the assembly; lap crossings trigger, reset position, and print the expected drift-diagnostic message; the loop doesn't crash or stall; SPI/I2C reads keep succeeding with all three sensors active simultaneously (this is the first point a bus conflict or timing budget problem would show up).

**If it fails:** this is the last stage where a bug is a pure software/wiring problem — everything after this also has mechanical and motor-EMI variables mixed in, which makes the same bug much harder to isolate.

---

## Stage 7 — Mechanical fixture fabrication (parallel-able with Stages 1–6)

**Goal:** a printed, populated front fixture, per `cad/fixture.scad` (`DESIGN.md` §7).

**Gate before printing:** the CAD open items in `DESIGN.md` §8 — real component footprints (from the boards actually used in Stages 3–5, not the typical/placeholder dimensions in the file today) and the real spine cross-section for `rear_splice()`. Printing before these are measured risks a fixture that doesn't fit the parts you've already validated.

**Procedure:** print, dry-fit the sensor boards and Pico without gluing/screwing anything permanent, confirm the standoffs/pockets match the real hardware.

**Pass:** everything physically fits with the clearances `DESIGN.md` flagged as tight (the rotated Pico's ~2mm margin in the 55mm spine section, specifically).

---

## Stage 8 — Full assembly + bench retest

**Goal:** confirm nothing broke moving from breadboard to the soldered/mounted fixture.

**Procedure:** mount and wire everything into the printed fixture per Stage 7, but power it from the bench/USB again first — not the track. Re-run Stage 6's dry-run check in this new physical form.

**Pass:** same as Stage 6. Any regression here is a mounting/wiring/solder-joint problem introduced during assembly, isolated from both the sensor logic (Stage 6 already passed) and the mechanical fit (Stage 7 already passed).

---

## Stage 9 — Off-power on-track fit check

**Goal:** validate the mechanical assumptions that only a real track can test — guide-flag engagement, skid behavior, and sensor standoff over real track surface texture — before adding rail power or the motor to the mix.

**Procedure:** cut the donor chassis (`DESIGN.md` §7) and complete the mechanical splice to the stock rear section, *if not already done as part of Stage 7's fabrication*. With the fixture's electronics still powered from a bench/USB supply (not the rails), place the assembled car in the slot and push it around by hand.

**Check specifically:**
- Guide flag pivots freely, doesn't bind, doesn't pop out of the slot on curves.
- Skid rides smoothly across track-piece seams (the ski-tip geometry from §7 doing its job).
- PMW3360 gets a stable, focused reading over the *real* track surface at the *real* ride height — a lab-desk test in Stage 3 does not substitute for this; track surface texture and lighting are different.
- IR sensor still cleanly detects the marker at the real ride height, not just on a bench jig.

**Pass:** all four hold up over a full hand-pushed lap.

**If the optical sensor doesn't track well here even though Stage 3 passed:** suspect focus height/lens standoff (§7's shim-to-tune note) or track surface reflectivity, not the driver.

---

## Stage 10 — First powered on-track run

**Goal:** rail power and the motor, together, for the first time — this is where motor EMI meeting sensitive SPI/I2C lines becomes a real risk that no earlier stage could test.

**Procedure:** connect to actual rail power via the guide-flag braids (§7's tap point). Low throttle, short run, one or two laps. Watch the serial output live if within cable/WiFi reach, or just let it log and pull the file after.

**Pass:** no SPI/I2C read failures or garbage data correlated with motor activity; supercap ride-through holds up under *real* throttle variation (not the bench-simulated version from Stage 2); a `track_log.csv` comes out with sane-looking numbers.

**If sensor reads glitch specifically when the motor is under load:** that's motor EMI coupling into the SPI/I2C lines — shielding, wire routing away from the motor, or added bypass capacitance near the sensor breakouts are the usual fixes, not a firmware change.

---

## Stage 11 — Full data-collection run + validation

**Goal:** the actual deliverable — a real multi-lap run producing a usable track map, with the lap length reported in metric units.

### How to run a data-collection session

1. **Apply the start/finish tape, across *all* lanes at the same cross-section, not just the one being driven.** A 40mm-wide reflective strip laid across the lane (`DESIGN.md` §6's sizing rule — narrower risks the car passing over it between samples and missing the lap entirely; re-check this width once Stage 5/10 have measured the real loop period and approach speed, per the same section). Pick a spot with a short straight or gentle curve on both sides, not right at the apex of a tight corner — it makes consistent, repeatable positioning of the car easier for the next step, and (mapping more than one lane) means every lane's run starts from the same physical line pointed the same approximate direction, which is what lets their separately-recorded vector paths be combined later (`DESIGN.md` §9).
2. **Place the car on the track roughly 1m before the tape**, sitting in the slot, pointed the right way — a rolling start, so the car is already up to a steady pace by the time it crosses the tape rather than accelerating from a dead stop right on the line.
3. **Power on and wait for gyro calibration to finish.** `main.py` prints `Calibrating gyro bias -- keep the car perfectly still for 1.5s...` and then a result line — the car must not be touched or moved during this window (`DESIGN.md` §6); if the result says `MOVED -- calibration unreliable`, power-cycle and redo this step before proceeding, since a bad calibration here is worse than none.
4. **Drive the car across the tape and continue for 5 complete laps** at a steady pace (`LAPS_TO_RECORD = 6` covers the rolling-start crossing plus 5 timed laps — see `main.py`'s comment on that constant). Multiple laps aren't needed for the gyro calibration itself (that already happened once, at rest, in step 3) — they're what `tools/closed_loop_correct.py --average-out` needs to average down the sensor-noise component of map error that per-lap correction alone doesn't reach (`DESIGN.md` §6). The firmware stops itself automatically after the 6th crossing.
5. **Retrieve `track_log.csv` off the board** before power-cycling it (`mpremote cp :track_log.csv .`, or via Thonny's file browser) — it's the only copy; the Pico's flash isn't otherwise backed up.

### How to post-process the log

6. **Determine `--net-turns` for the real track once** (not per run) by inspecting the driven lane itself: does its own centerline cross itself anywhere, or is it a simple loop? A plain oval, or a lane that merely swaps sides with an *adjacent* lane at a lane-equalizing crossover piece, is `+1.0` (or `-1.0`, depending on direction) — its own path is still a simple loop. Only a lane whose own path genuinely loops back and crosses itself gets a different value (`DESIGN.md` §6 has the full reasoning, and worked this out to `0.0` for the Bolton track's SVG-plan lane used in this project's own simulation — re-derive it for whatever's actually built, since the built track may not match that plan exactly).
7. **Run the closed-loop correction, with averaging:**
   ```
   python3 tools/closed_loop_correct.py track_log.csv --net-turns <value> \
       -o track_log_corrected.csv --average-out track_log_averaged.csv
   ```
   This prints each lap's corrected length in meters, then a summary line like `Lap length: mean 36.349 m over 5 lap(s) (min 36.324, max 36.356, spread 0.032 m)` — **that mean is the measured lap length**, and a small spread relative to the mean is itself a useful sanity check (real, physical measurement noise from an actual run will be larger than this project's simulation shows, so judge it by whether it's small *relative to the track's scale*, not against the simulated figure specifically). Treat `track_log_averaged.csv`'s own length figure as a smoothed map shape for visualization, not a more authoritative length source — see the tool's `--average-out` help text for why.
8. **Plot it:**
   ```
   python3 tools/plot_track_csv.py track_log_corrected.csv
   ```
   Open the resulting `.svg` in a browser.

**Pass:** the plotted shape resembles the actual track layout; the reported lap length is close to the track's known/expected length if there is one to compare against (or at least plausible for its physical size); and the per-lap length spread from step 7 is small relative to the mean. If the spread is large, or the plotted per-lap shapes visibly disagree with each other, heading drift is worse than `DESIGN.md` §2/§6's simulation assumed, and the second-marker heading-correction upgrade mentioned there stops being optional.

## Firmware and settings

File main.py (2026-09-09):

"""Track-mapper firmware: fuses the PMW3360 (translation) with the
ICM-42688-P's gyro (heading) into a dead-reckoned path, resets position at
each lap-marker crossing, and logs the result to a CSV file on the Pico's
flash. See DESIGN.md SS2 and SS6 for the fusion/lap-detection design this
implements, and SS7 for where the pin assignments and lever-arm distance
below come from.

NOT YET TESTED ON REAL HARDWARE. Known calibration steps before trusting
the output:
  - LAP_THRESHOLD is a guess -- print ir.read_u16() while passing the real
    marker by hand and set this from the actual light/dark ADC values.
  - Gyro sign/axis and optical dx/dy axis mapping depend on exactly how
    the ICM-42688-P and PMW3360 end up oriented on the fixture -- rotate
    the car by hand and push it straight forward by hand to confirm
    theta and (dx, dy) move the way this file assumes before trusting a
    real run (see the fusion loop below for the assumed convention).

Gyro bias is measured automatically at the start of every run (see
calibrate_gyro_bias() and DESIGN.md SS6) -- keep the car completely still
during the "Calibrating gyro bias" prompt printed at startup. This corrects
the dominant, systematic drift term (see DESIGN.md SS6 for why it matters);
it does not chase bias that wanders over the course of a long run.
"""

import time
import math
from machine import Pin, SPI, I2C, ADC

from pmw3360 import PMW3360
from icm42688 import ICM42688

SPI_SCK = 10
SPI_MOSI = 11
SPI_MISO = 12
PMW_CS = 13
# GPIO14 (PMW3360 MOTION) and GPIO6 (ICM interrupt) are wired but not used
# yet -- this first pass polls both sensors every loop instead.

I2C_SDA = 4
I2C_SCL = 5

IR_ADC_PIN = 26

# PMW3360-to-guide-pivot offset along the body's forward axis, from the
# fixture CAD (DESIGN.md SS2, SS7) -- re-measure if the layout changes.
LEVER_ARM_MM = 18.0

GYRO_CAL_DURATION_MS = 1500     # DESIGN.md SS6 -- measured fresh every run, not cached across power cycles
GYRO_CAL_MAX_ACCEL_STD_G = 0.03  # stillness check threshold -- tune once the real accelerometer noise floor is known

LAP_THRESHOLD = 30000    # ADC counts (0-65535) -- PLACEHOLDER, calibrate against the real marker
LAP_DEBOUNCE_MS = 1000   # ignore retriggers faster than this (DESIGN.md SS6)
# 6 = a rolling start (car ~1m before the tape, up to pace before crossing)
# plus 5 complete timed laps: the 1st crossing zeroes (x,y) and starts lap 1,
# the 6th crossing ends lap 5 and stops. Everything logged before the 1st
# crossing (lap == 0) is the rollout, not a timed lap -- keep it in the CSV
# (useful for sanity checking approach speed/behavior) but filter it out of
# any lap-shape analysis. 5 laps gives tools/closed_loop_correct.py's
# --average-out enough independent laps to average down sensor noise
# (BRINGUP.md's data-collection procedure) -- lower it back to 2 for a quick
# single-lap check instead.
LAPS_TO_RECORD = 6
MAX_RUN_MS = 5 * 60 * 1000  # safety cutoff if the lap sensor never fires

LOG_PATH = "track_log.csv"
FLUSH_EVERY = 50  # samples between flushes, so a mid-run brownout loses at most this many


def calibrate_gyro_bias(icm, duration_ms=GYRO_CAL_DURATION_MS):
    """Average the stationary gyro Z reading to find its static bias
    (DESIGN.md SS6) -- a modest, realistic 0.3 dps bias, uncorrected, was
    enough to produce roughly a meter of reconstructed-position error over a
    single 12.5s lap in sim/simulate_track_run.py. Also checks accelerometer
    variance over the same window so a bias measured while the car was being
    moved -- worse than no calibration at all -- is at least detectable.

    Returns (gz_bias_dps, was_still).
    """
    print("Calibrating gyro bias -- keep the car perfectly still for %.1fs..." % (duration_ms / 1000))
    start_ms = time.ticks_ms()
    n = 0
    gz_sum = 0.0
    ax_sum = ay_sum = az_sum = 0.0
    ax_sq_sum = ay_sq_sum = az_sq_sum = 0.0

    while time.ticks_diff(time.ticks_ms(), start_ms) < duration_ms:
        ax, ay, az = icm.read_accel_g()
        _, _, gz = icm.read_gyro_dps()
        gz_sum += gz
        ax_sum += ax
        ay_sum += ay
        az_sum += az
        ax_sq_sum += ax * ax
        ay_sq_sum += ay * ay
        az_sq_sum += az * az
        n += 1

    if n == 0:
        raise RuntimeError("Gyro calibration got no samples -- check IMU wiring")

    gz_bias = gz_sum / n
    ax_var = ax_sq_sum / n - (ax_sum / n) ** 2
    ay_var = ay_sq_sum / n - (ay_sum / n) ** 2
    az_var = az_sq_sum / n - (az_sum / n) ** 2
    accel_std = math.sqrt(max(0.0, ax_var + ay_var + az_var))

    was_still = accel_std < GYRO_CAL_MAX_ACCEL_STD_G
    print("Gyro bias = %.4f dps (n=%d samples), accel std = %.4f g (%s)"
          % (gz_bias, n, accel_std, "still" if was_still else "MOVED -- calibration unreliable"))
    return gz_bias, was_still


def run():
    spi = SPI(1, baudrate=2_000_000, polarity=1, phase=1,
              sck=Pin(SPI_SCK), mosi=Pin(SPI_MOSI), miso=Pin(SPI_MISO))
    pmw = PMW3360(spi, PMW_CS)
    print("Initializing PMW3360...")
    product_id, srom_id = pmw.begin()
    print("PMW3360 OK: product_id=0x%02x srom_id=0x%02x" % (product_id, srom_id))

    i2c = I2C(0, sda=Pin(I2C_SDA), scl=Pin(I2C_SCL), freq=400_000)
    icm = ICM42688(i2c)
    print("Initializing ICM-42688-P...")
    who = icm.begin()
    print("ICM-42688-P OK: WHO_AM_I=0x%02x" % who)

    ir = ADC(Pin(IR_ADC_PIN))

    gz_bias, gyro_cal_ok = calibrate_gyro_bias(icm)
    if not gyro_cal_ok:
        print("WARNING: car moved during gyro calibration -- heading will drift faster than DESIGN.md SS6 expects.")

    x = 0.0
    y = 0.0
    theta = 0.0  # radians; 0 = the heading the car is sitting at when this starts
    lap = 0
    ir_above = False
    last_lap_ms = 0
    sample_count = 0

    print("Recording -- drive %d lap(s), or waits up to %ds." % (LAPS_TO_RECORD, MAX_RUN_MS // 1000))
    start_ms = time.ticks_ms()
    t_prev = time.ticks_us()

    log = open(LOG_PATH, "w")
    log.write("t_ms,x_mm,y_mm,theta_rad,lap\n")

    try:
        while lap < LAPS_TO_RECORD:
            now_ms = time.ticks_ms()
            if time.ticks_diff(now_ms, start_ms) > MAX_RUN_MS:
                print("MAX_RUN_MS exceeded with no lap trigger -- stopping, saving what we have.")
                break

            t_now = time.ticks_us()
            dt = time.ticks_diff(t_now, t_prev) / 1_000_000
            t_prev = t_now

            _, _, gz_dps = icm.read_gyro_dps()
            gz_dps -= gz_bias  # DESIGN.md SS6 -- remove the static bias measured at startup
            gz_rad_s = math.radians(gz_dps)
            dtheta = gz_rad_s * dt
            theta += dtheta

            dx_counts, dy_counts = pmw.read_motion()
            dx_mm = pmw.counts_to_mm(dx_counts)
            dy_mm = pmw.counts_to_mm(dy_counts)

            # Recover the guide-pivot's displacement from the sensor's own,
            # using this tick's rotation (DESIGN.md SS2):
            #   v_pivot = v_sensor - omega x r,  r = (LEVER_ARM_MM, 0) body-frame
            dx_pivot = dx_mm
            dy_pivot = dy_mm - dtheta * LEVER_ARM_MM

            # Rotate the body-frame displacement into the world frame and
            # integrate (theta: 0=start heading, +ve = CCW, matches a
            # right-handed Z-up gyro axis -- flip gz's sign here if a
            # by-hand rotation test shows it backwards).
            cos_t = math.cos(theta)
            sin_t = math.sin(theta)
            x += dx_pivot * cos_t - dy_pivot * sin_t
            y += dx_pivot * sin_t + dy_pivot * cos_t

            ir_value = ir.read_u16()
            if (ir_value > LAP_THRESHOLD and not ir_above
                    and time.ticks_diff(now_ms, last_lap_ms) > LAP_DEBOUNCE_MS):
                ir_above = True
                last_lap_ms = now_ms
                lap += 1
                print("Lap %d/%d at t=%dms (drift before reset: x=%.1fmm y=%.1fmm)"
                      % (lap, LAPS_TO_RECORD, now_ms, x, y))
                x = 0.0
                y = 0.0
            elif ir_value <= LAP_THRESHOLD:
                ir_above = False

            log.write("%d,%.2f,%.2f,%.4f,%d\n" % (now_ms, x, y, theta, lap))
            sample_count += 1
            if sample_count % FLUSH_EVERY == 0:
                log.flush()
    finally:
        log.flush()
        log.close()

    print("Done: %d samples, %d lap(s) recorded to %s" % (sample_count, lap, LOG_PATH))
    print("Retrieve the file with mpremote/Thonny/ampy before power-cycling the board.")


run()

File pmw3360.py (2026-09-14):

"""PMW3360 optical flow sensor driver (SPI), for the track-mapper fusion loop.

Register map, timing constants, and the init/motion-burst sequence follow
the widely-ported open-source PMW3360 reference driver (SunjunKim's Arduino
library and its many forks) -- not independently verified against the
datasheet (tmp/C20612443.pdf) on real hardware. SROM_FIRMWARE below is the
real SROM 0x04 firmware blob, copied byte-for-byte from SunjunKim/PMW3360's
src/PMW3360.cpp (https://github.com/SunjunKim/PMW3360, LGPL-2.1 -- the
canonical, actively-maintained library this driver's register map and
timing already follow) -- the same technique a6_binary.py used to embed the
ADNS-9800's SROM, just already done here. Still not run on real hardware;
check timing constants before trusting this on a board.

Cross-checked against QMK's PMW33xx driver (qmk/qmk_firmware,
drivers/sensors/pmw3360.c + pmw33xx_common.c, GPL-2.0-or-later), which is
deployed on real trackball keyboards using this same sensor. QMK doesn't
carry the actual SROM byte content in-tree (removed for licensing reasons;
it's opt-in and keyboard-supplied, from this same SunjunKim/PMW3360 source),
so it can't byte-diff SROM_FIRMWARE -- but its constants do independently
corroborate this blob: PMW33XX_FIRMWARE_LENGTH is 4094, matching
len(SROM_FIRMWARE) here, and its firmware signature {0x42, 0xBD} matches
EXPECTED_PRODUCT_ID/EXPECTED_INVERSE_PRODUCT_ID below. Its register map
(pmw3360.h) matches ours address-for-address. Two sequencing details from
its init(), proven across real hardware, were folded in here: the NCS
low/high power-up toggle before Power_Up_Reset, and its more conservative
post-write settle timing (tSCLK-NCS + tSWW/tSWR margins) in _write().
"""

from machine import Pin
import time

REG_PRODUCT_ID = 0x00
REG_REVISION_ID = 0x01
REG_MOTION = 0x02
REG_DELTA_X_L = 0x03
REG_DELTA_X_H = 0x04
REG_DELTA_Y_L = 0x05
REG_DELTA_Y_H = 0x06
REG_SQUAL = 0x07
REG_CONFIG1 = 0x0F
REG_CONFIG2 = 0x10
REG_SROM_ENABLE = 0x13
REG_SROM_ID = 0x2A
REG_POWER_UP_RESET = 0x3A
REG_INVERSE_PRODUCT_ID = 0x3F
REG_MOTION_BURST = 0x50
REG_SROM_LOAD_BURST = 0x62

EXPECTED_PRODUCT_ID = 0x42
# Signature for SROM 0x04 (SunjunKim/PMW3360's check_signature()) -- verifying
# both of these plus the SROM ID below catches a bad/partial upload that a
# product-ID-only check would miss.
EXPECTED_INVERSE_PRODUCT_ID = 0xBD
EXPECTED_SROM_ID = 0x04

# SROM 0x04 firmware blob -- see module docstring for provenance. Every
# reference driver uploads one of these; a wrong/missing one means the
# sensor will not track reliably, or at all.
SROM_FIRMWARE = bytes([
    0x01, 0x04, 0x8e, 0x96, 0x6e, 0x77, 0x3e, 0xfe, 0x7e, 0x5f, 0x1d, 0xb8,
    0xf2, 0x66, 0x4e, 0xff, 0x5d, 0x19, 0xb0, 0xc2, 0x04, 0x69, 0x54, 0x2a,
    0xd6, 0x2e, 0xbf, 0xdd, 0x19, 0xb0, 0xc3, 0xe5, 0x29, 0xb1, 0xe0, 0x23,
    0xa5, 0xa9, 0xb1, 0xc1, 0x00, 0x82, 0x67, 0x4c, 0x1a, 0x97, 0x8d, 0x79,
    0x51, 0x20, 0xc7, 0x06, 0x8e, 0x7c, 0x7c, 0x7a, 0x76, 0x4f, 0xfd, 0x59,
    0x30, 0xe2, 0x46, 0x0e, 0x9e, 0xbe, 0xdf, 0x1d, 0x99, 0x91, 0xa0, 0xa5,
    0xa1, 0xa9, 0xd0, 0x22, 0xc6, 0xef, 0x5c, 0x1b, 0x95, 0x89, 0x90, 0xa2,
    0xa7, 0xcc, 0xfb, 0x55, 0x28, 0xb3, 0xe4, 0x4a, 0xf7, 0x6c, 0x3b, 0xf4,
    0x6a, 0x56, 0x2e, 0xde, 0x1f, 0x9d, 0xb8, 0xd3, 0x05, 0x88, 0x92, 0xa6,
    0xce, 0x1e, 0xbe, 0xdf, 0x1d, 0x99, 0xb0, 0xe2, 0x46, 0xef, 0x5c, 0x07,
    0x11, 0x5d, 0x98, 0x0b, 0x9d, 0x94, 0x97, 0xee, 0x4e, 0x45, 0x33, 0x6b,
    0x44, 0xc7, 0x29, 0x56, 0x27, 0x30, 0xc6, 0xa7, 0xd5, 0xf2, 0x56, 0xdf,
    0xb4, 0x38, 0x62, 0xcb, 0xa0, 0xb6, 0xe3, 0x0f, 0x84, 0x06, 0x24, 0x05,
    0x65, 0x6f, 0x76, 0x89, 0xb5, 0x77, 0x41, 0x27, 0x82, 0x66, 0x65, 0x82,
    0xcc, 0xd5, 0xe6, 0x20, 0xd5, 0x27, 0x17, 0xc5, 0xf8, 0x03, 0x23, 0x7c,
    0x5f, 0x64, 0xa5, 0x1d, 0xc1, 0xd6, 0x36, 0xcb, 0x4c, 0xd4, 0xdb, 0x66,
    0xd7, 0x8b, 0xb1, 0x99, 0x7e, 0x6f, 0x4c, 0x36, 0x40, 0x06, 0xd6, 0xeb,
    0xd7, 0xa2, 0xe4, 0xf4, 0x95, 0x51, 0x5a, 0x54, 0x96, 0xd5, 0x53, 0x44,
    0xd7, 0x8c, 0xe0, 0xb9, 0x40, 0x68, 0xd2, 0x18, 0xe9, 0xdd, 0x9a, 0x23,
    0x92, 0x48, 0xee, 0x7f, 0x43, 0xaf, 0xea, 0x77, 0x38, 0x84, 0x8c, 0x0a,
    0x72, 0xaf, 0x69, 0xf8, 0xdd, 0xf1, 0x24, 0x83, 0xa3, 0xf8, 0x4a, 0xbf,
    0xf5, 0x94, 0x13, 0xdb, 0xbb, 0xd8, 0xb4, 0xb3, 0xa0, 0xfb, 0x45, 0x50,
    0x60, 0x30, 0x59, 0x12, 0x31, 0x71, 0xa2, 0xd3, 0x13, 0xe7, 0xfa, 0xe7,
    0xce, 0x0f, 0x63, 0x15, 0x0b, 0x6b, 0x94, 0xbb, 0x37, 0x83, 0x26, 0x05,
    0x9d, 0xfb, 0x46, 0x92, 0xfc, 0x0a, 0x15, 0xd1, 0x0d, 0x73, 0x92, 0xd6,
    0x8c, 0x1b, 0x8c, 0xb8, 0x55, 0x8a, 0xce, 0xbd, 0xfe, 0x8e, 0xfc, 0xed,
    0x09, 0x12, 0x83, 0x91, 0x82, 0x51, 0x31, 0x23, 0xfb, 0xb4, 0x0c, 0x76,
    0xad, 0x7c, 0xd9, 0xb4, 0x4b, 0xb2, 0x67, 0x14, 0x09, 0x9c, 0x7f, 0x0c,
    0x18, 0xba, 0x3b, 0xd6, 0x8e, 0x14, 0x2a, 0xe4, 0x1b, 0x52, 0x9f, 0x2b,
    0x7d, 0xe1, 0xfb, 0x6a, 0x33, 0x02, 0xfa, 0xac, 0x5a, 0xf2, 0x3e, 0x88,
    0x7e, 0xae, 0xd1, 0xf3, 0x78, 0xe8, 0x05, 0xd1, 0xe3, 0xdc, 0x21, 0xf6,
    0xe1, 0x9a, 0xbd, 0x17, 0x0e, 0xd9, 0x46, 0x9b, 0x88, 0x03, 0xea, 0xf6,
    0x66, 0xbe, 0x0e, 0x1b, 0x50, 0x49, 0x96, 0x40, 0x97, 0xf1, 0xf1, 0xe4,
    0x80, 0xa6, 0x6e, 0xe8, 0x77, 0x34, 0xbf, 0x29, 0x40, 0x44, 0xc2, 0xff,
    0x4e, 0x98, 0xd3, 0x9c, 0xa3, 0x32, 0x2b, 0x76, 0x51, 0x04, 0x09, 0xe7,
    0xa9, 0xd1, 0xa6, 0x32, 0xb1, 0x23, 0x53, 0xe2, 0x47, 0xab, 0xd6, 0xf5,
    0x69, 0x5c, 0x3e, 0x5f, 0xfa, 0xae, 0x45, 0x20, 0xe5, 0xd2, 0x44, 0xff,
    0x39, 0x32, 0x6d, 0xfd, 0x27, 0x57, 0x5c, 0xfd, 0xf0, 0xde, 0xc1, 0xb5,
    0x99, 0xe5, 0xf5, 0x1c, 0x77, 0x01, 0x75, 0xc5, 0x6d, 0x58, 0x92, 0xf2,
    0xb2, 0x47, 0x00, 0x01, 0x26, 0x96, 0x7a, 0x30, 0xff, 0xb7, 0xf0, 0xef,
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
])
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

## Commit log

2026-09-03 Design docs, CAD, schematic, and firmware for the track mapper
    Adds the full design record (DESIGN.md, CLAUDE.md, BRINGUP.md) covering
    sensor/MCU selection, power delivery, lap detection, and the donor-chassis
    fixture plan; a parametric OpenSCAD fixture model (cad/); a KiCad system
    schematic (electronics/, ERC-clean); and a first-pass MicroPython fusion
    loop (main.py, pmw3360.py, icm42688.py) implementing the PMW3360+IMU dead
    reckoning design. Untested on real hardware -- see BRINGUP.md for the
    staged validation plan and each new file's docstring/comments for known
    placeholders (PMW3360 SROM firmware, LAP_THRESHOLD, several CAD/regulator
    values pending real parts).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
    [electronics.kicad_sch, fixture.scad]
2026-09-04 Add track-run simulator and gyro-bias calibration
    Add sim/simulate_track_run.py, which parses the real Bolton club track's
    SVG (tmp/bolton-track.svg) and synthesizes a lap's worth of expected
    PMW3360/ICM-42688-P/IR sensor data (sim/expected_track_run.csv) from a
    curvature-limited speed profile, including realistic sensor noise/bias
    and lever-arm kinematics matching main.py. Re-running main.py's own
    fusion math against the synthetic data as a validation step surfaced a
    real gap: a modest, realistic gyro bias alone measurably distorts the
    reconstructed path.
    Add calibrate_gyro_bias() to main.py, run once at startup before the
    fusion loop: averages the stationary gyro Z reading over a short wi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
    [expected_track_run.csv]
2026-09-04 Size the lap-marker tape to the sampling, and use a rolling-start capture
    DESIGN.md SS6: main.py's loop is unthrottled, so its real sample period
    is unmeasured, not just uncalibrated. Add a sizing rule for the
    start/finish tape (width >= v*T to avoid missing a crossing outright,
    2*v*T for margin) and recommend a 40mm starting width, confirmed against
    the simulator (now catches 2 samples per crossing vs 1 at the old 12mm).
    main.py: LAPS_TO_RECORD 3 -> 2, matching a rolling-start workflow (car
    placed ~1m before the tape, up to pace before the first crossing, which
    zeroes the origin and starts the timed lap; the second crossing ends it
    after exactly one lap) rather than the previous 3-crossing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
    [expected_track_run.csv]
2026-09-04 Add CSV-to-SVG track plotter; fix a frame bug it caught
    Add tools/plot_track_csv.py, a dependency-free renderer for either CSV
    shape this project produces: the firmware's on-device track_log.csv
    (one polyline per lap) or the simulator's expected_track_run.csv (ground
    truth overlaid with the reconstructed path).
    Building the overlay view surfaced a real bug in how "reconstructed vs.
    ground truth" was being compared: main.py's (x,y) output has its x-axis
    aligned to the car's own initial heading, not the world/SVG's absolute
    X axis. Overlaying the two without correcting for that fixed rotation
    made the reconstruction look far worse than it is -- fixed in both the
    new plotting tool and sim/simu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
2026-09-04 Closed-loop heading correction, second guide pin, BOM, and how-to docs
    - tools/closed_loop_correct.py: offline closed-loop gyro-bias correction
    per completed lap (a lap's net heading change is a known geometric
    quantity, not a free parameter), needing no firmware change since
    main.py already logs enough to recover it. Reports per-lap length in
    meters and cross-lap spread, and can average multiple laps into one
    smoothed shape.
    - sim/simulate_track_run.py: now simulates 5 continuous laps and also
    emits a firmware-log-shaped CSV, so the above could be tested against
    realistic multi-lap data instead of assumed to work. Fixed two bugs
    found in the process (a tape-detection float-p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
    [expected_firmware_log.csv, expected_track_run.csv, fixture.scad]
2026-09-04 Correct DESIGN.md: no such thing as a constant-voltage accessory rail
    Slot car tracks never carry a third, constant-voltage rail alongside the
    two throttle rails -- removes the false "check for one" suggestion in SS4
    and the now-invalid open item in SS8. The buck-boost + supercap design is
    the actual answer to the power problem, not a fallback for a shortcut
    that was never available.
    Claude-Session: https://claude.ai/code/session_016Jit9Jrne7RQVV3mn469qj
2026-09-07 Fixture: mirror motor-carrier profile at rear, mount PMW3360 lens per datasheet
    The fixture's rear edge now notches to match the real motor carrier's
    wedge-and-tab shape (caliper-measured), forming a flush self-aligning
    joint instead of a flat placeholder splice — elongating the fixture so
    the Pico/sensor zone ahead of it keeps the same usable length. The
    dummy rear guide pin is dropped in favor of a pre-existing hole in the
    carrier itself.
    The PMW3360 mount is reworked from a generic hanging placeholder to
    match the real PMW3360DM-T2QU + LM19-LSI datasheet (tmp/C20612443.pdf):
    the sensor PCB mounts above the deck on standoffs, with only the lens
    dropping through a stepped pocket (proper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
    [fixture.scad]
2026-09-07 Fixture: consolidate electronics onto one shared strip-board PCB
    The deck now explicitly plays the role of the PMW3360 datasheet's
    "Customer Supplied Base Plate with Recommended Opening" (Fig. 8),
    documented as such in the header. Adds shared_pcb(): a single 1.11mm
    strip board mounted on standoffs above the deck (Fig. 4's PCB-to-base-
    plate gap) carrying the Pico 2 W, PMW3360, ICM-42688-P, and IR lap
    sensor together, wired point-to-point along its copper strips instead
    of as four separate breakouts — replacing the old individual
    pico_mount()/icm_mount()/pmw_chip_visual().
    The IR sensor is sized from real datasheets (tmp/QRE1113.pdf,
    tmp/TCRT5000.pdf): QRE1113's low-profile through-hole bo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
    [fixture.scad]
2026-09-09 pmw3360.py: replace SROM_FIRMWARE placeholder with the real firmware blob
    SROM_FIRMWARE was 4094 zero bytes; the sensor would never track with
    it. Replaced with the real SROM 0x04 firmware, copied byte-for-byte
    from SunjunKim/PMW3360's src/PMW3360.cpp (LGPL-2.1) — the canonical,
    actively-maintained Arduino library this driver's register map and
    timing already follow, and the same repo its own docstring already
    named as the source to use.
    Also adopted that library's stronger post-upload signature check in
    begin(): product ID, inverse product ID (0xBD), and SROM ID (0x04),
    rather than just product ID and a nonzero SROM ID — catches a bad or
    partial firmware upload the old check would have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
    [main.py, pmw3360.py]
2026-09-09 DESIGN.md: update stale PMW3360 SROM firmware references
    pmw3360.py's SROM_FIRMWARE stopped being a placeholder last session
    (real SROM 0x04 blob from SunjunKim/PMW3360), but DESIGN.md still had
    three references treating it as an open item: §3's "will be replaced
    when firmware work starts", §6's calibration list, and an §8 open-item
    bullet. Updated all three to reflect the current state and dropped the
    now-complete §8 bullet.
    Claude-Session: https://claude.ai/code/session_01VB3CcWWzDiHBSoPq5HJz8G
2026-09-14 pmw3360.py: cross-check driver against QMK's PMW33xx driver
    QMK's driver (deployed on real trackball keyboards) doesn't ship the SROM
    byte content itself, but its constants corroborate this one: firmware
    length (4094 bytes) and product/inverse-ID signature (0x42/0xBD) both
    match. Folded in two sequencing details from its init()/write() that this
    port was missing: the NCS power-up toggle before Power_Up_Reset, and more
    conservative post-write settle timing.
    Claude-Session: https://claude.ai/code/session_01JriPYQQzv2MciVZcp9woc3
    [pmw3360.py]
2026-09-14 DESIGN.md: cross-check PMW3360 electronics against Ploopy's open-hardware trackball
    Ploopy's ploopyco/classic-trackball (CERN-OHL-1.2) wires the bare
    PMW3360DM-T2QU directly and needs three rails (VDD 1.8V, VDDIO 3.3V,
    VDDPIX 1.8V through an RC filter) plus a CS pull-up. Confirms buying a
    breakout instead of laying out the bare chip is the right call, and
    surfaces a cheap CS-pull-up improvement to carry over regardless -
    tracked as a new §8 open item.
    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
